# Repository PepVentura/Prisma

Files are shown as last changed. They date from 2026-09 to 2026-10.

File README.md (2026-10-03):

# Prisma
Asistente inteligente de sobremesa con Raspberry Pi 5, pantalla táctil de 7", avatar 3D y audio integrado.

**Estado actual: v0.6.** Todas las piezas de la carcasa son imprimibles: cubeta, bandeja, caja superior, capucha y piezas pequeñas. Las cotas del altavoz y del radiador se confirmarán con las piezas reales.

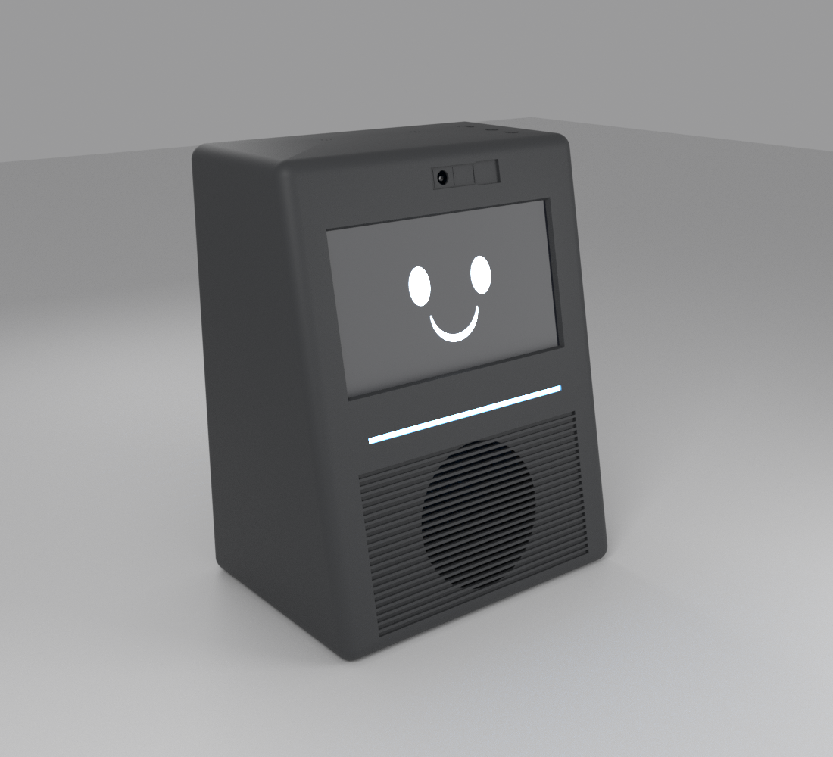
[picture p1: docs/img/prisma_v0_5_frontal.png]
Prisma v0.5


## Hardware
- Raspberry Pi 5 8 GB — confirmado
- Waveshare 7inch HDMI LCD (C), 1024×600 — recibido
- Dayton DMA105-4 — pedido
- Dayton DMA105-PR — pedido
- Dayton KABD-250 — pedido
- DAC GY-PCM5102 (PCM5102A, I²S) — propuesto
- ReSpeaker Lite USB (2 micrófonos con AEC) — propuesto
- WS2812B: barra de 8–12 LEDs y dos franjas de tira de 5 mm en los cantos (D033) — propuesto
- Cámara OV5647 5 MP, sobre la pantalla — disponible
- Fuente Mean Well GST60A24-P1J (24 V, 60 W) — propuesta
- Conversor Pololu D36V50F5 (24→5 V, 5,5 A) — propuesto

## Arquitectura
```text
Pantalla → Raspberry Pi 5 → DAC → KABD-250 → DMA105-4
                 │
                 ├── micrófonos
                 ├── LEDs
                 └── cámara
```

## Diseño (v0.5)
Frontal inclinado de arriba abajo, aristas redondeadas y negro mate, como el boceto original:
- **Arriba:** cámara con tapa deslizante y micrófonos en el techo.
- **Centro:** pantalla de 7" en horizontal.
- **Debajo:** franja LED y banda de lamas con el altavoz detrás.
- **Cantos del frontal:** dos franjas transparentes iluminadas por LEDs; el color indica el estado (escucha, pensando, silencio…).
- **Techo:** volumen y silencio de micrófonos.
- **Trasera:** ventilación, alimentación, botón de encendido y radiador pasivo.

Medidas: **205 × 262 × 150 mm**. Cámara acústica de ≈3,1 L netos. Dentro de la carcasa solo entra 24 V; la fuente de red es externa.

## CAD
`enclosure/openscad/prisma_volumetrica_v0_3.scad` es una maqueta de distribución, no la carcasa final.

`tools/comprobar_volumetrico.py` mide el volumen neto de la cámara y comprueba interferencias entre componentes.

Piezas imprimibles: la capucha (`enclosure/openscad/capucha.scad`, ver `docs/14_capucha.md`), la cubeta acústica (`enclosure/openscad/cubeta.scad`, ver `docs/15_cubeta.md`) y la bandeja, la caja superior y la balda del KABD (`bandeja.scad`, `caja_superior.scad`, ver `docs/16_bandeja_caja.md`).

`tools/simulacion_audio.py` simula la respuesta en graves del altavoz y el radiador en la cámara (ver `docs/05_audio.md`).

Consulta `docs/DECISIONS.md`, `docs/08_distribucion.md` y `docs/BOM.md`.

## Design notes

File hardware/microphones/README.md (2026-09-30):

# Micrófonos
ReSpeaker Lite USB (XMOS XU316, 2 micrófonos, AEC por hardware), 86 × 35 mm, bajo el techo. Ver `docs/10_electronica.md`.

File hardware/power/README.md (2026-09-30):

# Alimentación
Fuente Mean Well GST60A24-P1J (24 V, 60 W, externa) + conector DC de panel + Pololu D36V50F5 (24 → 5 V, 5,5 A). Presupuesto de consumo en `docs/10_electronica.md`.

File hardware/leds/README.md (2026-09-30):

# LEDs
WS2812B, 8–12 unidades inicialmente.

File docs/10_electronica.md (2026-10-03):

# 10 — Electrónica

## Esquema
```text
Fuente 24 V externa (GST60A24, 60 W)
   │  conector DC de panel (trasera)
   ├──────────────► KABD-250 (amplificador + DSP) ──► DMA105-4
   │                     ▲ entrada AUX analógica
   └─► Pololu D36V50F5 (24 → 5 V, 5,5 A)
          ├─► Raspberry Pi 5 (USB-C)
          │      ├─ I²S ──► GY-PCM5102 (DAC) ──► jack 3,5 mm ──► AUX del KABD-250
          │      ├─ HDMI + USB ──► pantalla Waveshare 7"
          │      ├─ USB ──► ReSpeaker Lite (micrófonos)
          │      ├─ CSI ──► Camera Module 3 (sobre la pantalla)
          │      └─ SPI (GPIO10) ──► 74AHCT125 ──► barra ──► franja izq. ──► franja der. (WS2812B)
          └─► alimentación de los LEDs (inyectada en la barra y en cada franja)
```

## Selección
| Función | Modelo | Por qué | Medidas |
|---|---|---|---|
| DAC | **GY-PCM5102** (PCM5102A) | El KABD-250 solo tiene entrada analógica y Bluetooth, sin I²S. Barato, bien soportado en la Pi 5 (`dtoverlay=hifiberry-dac`), 112 dB SNR, salida jack de 2,1 V rms | 32 × 14 mm |
| Micrófonos | **ReSpeaker Lite USB** (XMOS XU316, 2 micrófonos) | Cancelación de eco, supresión de ruido y ganancia automática por hardware, por USB. El XVF3800 (4 micrófonos) es mejor, pero su placa de 99 mm no cabe bajo el techo con la pantalla inclinada delante | 86 × 35 mm |
| Conversor 24 → 5 V | **Pololu D36V50F5** | 5 V, 5,5 A, entrada de 5,5 a 50 V, 80–95 % de rendimiento, muy compacto | 25,4 × 25,4 × 9,5 mm |
| Fuente | **Mean Well GST60A24-P1J** | 24 V, 2,5 A, 60 W, de sobremesa, clavija 5,5 × 2,1 mm. Da un 60 % de margen sobre el pico calculado | externa |
| Cámara | **OV5647 5 MP** (compatible con la cámara oficial v1.3; ya la tienes) | Foco fijo, 1080p. Suficiente para detectar caras y videollamadas. La Camera Module 3 (autofoco, 12 MP) tiene la misma placa y encaja en el mismo soporte | 25 × 24 mm, unos 9 mm de fondo |
| LEDs | Barra WS2812B (8–12) + 2 franjas de tira WS2812B de 5 mm a 160 LED/m (≈36 LEDs cada una, D033) + **SN74AHCT125** | La Pi da 3,3 V y los WS2812B esperan 5 V en datos: el 74AHCT125 adapta el nivel | — |

## Presupuesto de consumo (estimación)
**Rama de 5 V**

| Consumidor | Pico estimado |
|---|---:|
| Raspberry Pi 5 + Active Cooler | 15 W |
| Pantalla Waveshare 7" | 3 W |
| ReSpeaker Lite | 0,5 W |
| DAC | < 0,1 W |
| ≈84 × WS2812B (barra + franjas), corriente limitada por software a 0,6 A | 3 W (≈25 W si se encendiesen todos en blanco al 100 %: no permitido) |
| **Total** | **≈ 21,5 W → 4,3 A a 5 V** (conversor de 5,5 A: margen de 1,2 A) |

**Rama de 24 V**

| Consumidor | Pico estimado |
|---|---:|
| Conversor (21,5 W / 0,9) | 24 W |
| KABD-250, un canal a ≈10 W (límite del Xmax, ver `05_audio.md`) | 13 W |
| **Total** | **≈ 37 W** (fuente de 60 W) |

El KABD-250 recomienda 4 A porque está pensado para 2 × 50 W. Aquí solo se usa un canal y el altavoz no admite más de unos 10 W en graves, así que 2,5 A sobran.

## Conexiones
### Alimentación de la Pi 5
- Del Pololu a la Pi con un cable USB-C corto (solo alimentación) y cable de 0,5 mm² o más grueso.
- La Pi 5 solo reconoce 5 A si la fuente lo anuncia por USB-PD, y el Pololu no lo hace. Para que los USB den su corriente completa (la pantalla y los micrófonos cuelgan de ellos):
  - EEPROM (`sudo rpi-eeprom-config --edit`): `PSU_MAX_CURRENT=5000`
  - `/boot/firmware/config.txt`: `usb_max_current_enable=1`

### DAC GY-PCM5102 → Pi 5
| DAC | Pi 5 (pin) |
|---|---|
| VIN | 3,3 V (1) |
| GND | GND (6) |
| BCK | GPIO18 (12) |
| LRCK | GPIO19 (35) |
| DIN | GPIO21 (40) |
| SCK | a GND (el PCM5102A genera el reloj internamente) |

`/boot/firmware/config.txt`: `dtoverlay=hifiberry-dac`. Del jack del DAC al AUX del KABD-250 con el cable de 3,5 mm que trae la placa.

### Barra WS2812B
- Datos: GPIO10 (SPI0 MOSI, pin 19) → 74AHCT125 alimentado a 5 V → resistencia de 330 Ω → DIN del primer LED.
- Condensador de 1000 µF entre 5 V y GND en la entrada de la barra.
- Franjas (D033): cada una son dos tramos, uno en la cubeta (≈15 LEDs) y otro en la capucha (≈21 LEDs), unidos en la junta con un conector JST de 3 pines para poder abrir la carcasa. Los datos bajan por la franja izquierda y vuelven a subir por un hilo fino dentro del canal hasta la franja derecha. Los cables salen a la bahía por el extremo superior de cada canal.
- Alimentación: 5 V y GND inyectados en la entrada de la barra y en lo alto de cada franja, con cable de 0,5 mm².
- **Límite de corriente obligatorio en el software:** 0,6 A en total para los LEDs (por ejemplo, brillo global máximo de 0,25 y nunca blanco a tope en todos). Sin ese límite podrían pedir más de 4 A y tumbar la Pi.
- La librería clásica `rpi_ws281x` no funciona en la Pi 5 (su chip de E/S, el RP1, es distinto). Se controla por SPI, por ejemplo con `adafruit-circuitpython-neopixel-spi`.

## Botones (D032)
| Botón | Conexión |
|---|---|
| Volumen − | Pulsador 6 × 6 entre GPIO5 (pin 29) y GND, con *pull-up* interno |
| Volumen + | Pulsador 6 × 6 entre GPIO6 (pin 31) y GND, con *pull-up* interno |
| Silencio de micrófonos | Interruptor SS12D00 en serie con el cable rojo (+5 V) del USB del ReSpeaker Lite: los micrófonos se apagan físicamente. Opcional: el otro polo del SS12D00 a GPIO13 (pin 33) para que el software sepa el estado |
| Encendido | Pulsador al conector `PWR BUT` (J2) de la Pi 5: pulsación corta apaga bien, otra la enciende |

## Audio: filtro y cancelación de eco
- **Filtro paso alto de 40 Hz (D022) y ecualización:** en la Pi, con CamillaDSP o un filtro de PipeWire. Así no hace falta el programador DSPB-ICP1 para el DSP del KABD-250, que se queda con sus ajustes por defecto y los potenciómetros.
- **Cancelación de eco:** el ReSpeaker Lite cancela el eco por hardware si recibe como referencia el mismo audio que suena. La música sale por el DAC, así que PipeWire envía una copia al ReSpeaker por USB; su salida queda sin conectar. Si esa vía no funciona bien, la alternativa es la cancelación de eco por software de PipeWire (`module-echo-cancel`, WebRTC), que funciona con cualquier micrófono.

## Cámara (D025)
**Ubicación:** centrada en la franja del frontal inclinado, justo encima del cristal de la pantalla.

Opciones descartadas:
| Ubicación | Por qué no |
|---|---|
| Techo | Mira hacia arriba y ya lo ocupan los micrófonos |
| Franja de LEDs, entre pantalla y altavoz | Solo 11 mm de alto, demasiado baja (vería al usuario desde abajo) y pegada al altavoz, que la haría vibrar |
| Laterales | Descentrada: la cara del usuario saldría de perfil y el seguimiento del avatar quedaría torcido |
| Módulo espía diminuto en los 12 mm libres sobre la pantalla | Cabría sin cambiar la carcasa, pero con un sensor antiguo (OV5647, sin autofoco) |

**Por qué encima de la pantalla:**
- mira de frente al usuario cuando mira la pantalla, como una webcam de portátil;
- queda a la mayor altura del aparato;
- comparte la inclinación de 18° de la pantalla, así que apunta ligeramente hacia arriba, hacia la cara de quien está sentado a la mesa;
- está lo más lejos posible del altavoz.

**Espacio:** en v0.5 la cámara cabe en el bisel superior del frontal inclinado; la altura total (262 mm) sale de apilar altavoz, bandeja, pantalla y cámara.

**Montaje:** la placa se atornilla por detrás del frontal (taladros M2 de la cámara) con el objetivo en un agujero de 8 mm. El cable plano baja por detrás de la pantalla hasta el conector CSI de la Pi.

**Privacidad (D026): tapa deslizante obligatoria.**
- Corredera de 16 × 12 mm en una guía en cola de milano rebajada 1,6 mm en el frontal. Queda casi enrasada y no se puede perder.
- Se desliza 14 mm hacia la derecha para descubrir el objetivo. Dos resaltes marcan las posiciones abierta y cerrada.
- Pieza de prueba para ajustar holguras antes del frontal definitivo: `enclosure/openscad/tapa_camara_prueba.scad` → `stl/tapa_camara_prueba_v0_1.stl`. Se imprimen la placa y la corredera planas, sin soportes; si la corredera va dura o floja, ajusta `clear`.
- Además, el software encenderá un LED de la barra mientras la cámara esté activa.

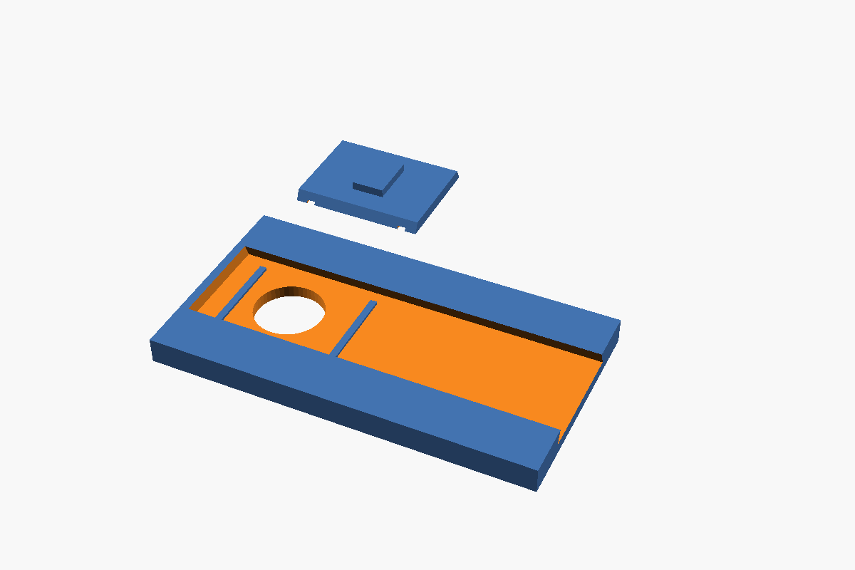
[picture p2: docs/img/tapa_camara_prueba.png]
Tapa de la cámara


## Pendiente
- Confirmar la separación real de los micrófonos del ReSpeaker Lite para situar los agujeros del techo.

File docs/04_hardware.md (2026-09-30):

# 04 — Hardware
La tabla de componentes y su estado se encuentra en `docs/BOM.md`.

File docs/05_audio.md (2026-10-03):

# 05 — Audio
## DMA105-4
4", 4 Ω, 35 W RMS. Transductor principal propuesto. Montado en el frontal inferior vertical (bafle), centrado a z ≈ 57 mm.

## DMA105-PR
4", radiador pasivo propuesto. Montado en la trasera inferior, coaxial con el DMA105-4 (D018). La trasera inferior queda libre: sin puertos, rejillas ni ventilador delante del radiador.

## Cámara acústica (D008, D016)
Forma en L:
- bloque inferior: ancho y fondo completos, de z = 3 a z = 111 mm;
- bloque superior-trasero: desde y = 60 mm hasta la trasera, de z = 111 a z = 176 mm, detrás de la pantalla.

**Actualización v0.6:** con la bandeja y la caja superior modeladas, el neto medido es de **3,08 L**. Simulación repetida: radiador + 10 g → 43,9 Hz, 10 W y 93,8 dB a 100 Hz. Sin cambios apreciables.

**Actualización v0.5:** con el frontal inclinado (D031) el altavoz queda inclinado 11° hacia el usuario y el neto final es de unos **3,13 L**. Los resultados de la simulación no cambian.

**Actualización v0.4:** con la cubeta real (anillos de montaje y aire delante de los conos), el neto final es de unos **3,1 L**. Repetida la simulación con 3,1 L, los resultados no cambian de forma apreciable. Ver `docs/15_cubeta.md`.

Volumen medido sobre el modelo v0.3 (`tools/comprobar_volumetrico.py`):

| Concepto | Litros |
|---|---:|
| Aire interior descontando DMA105-4 y DMA105-PR | 3,40 |
| Reserva para refuerzos, espuma y cableado | −0,10 |
| **Volumen neto estimado** | **≈ 3,30** |

Dentro del objetivo de 3–4 L. El desplazamiento de los transductores se modela como troncos de cono conservadores; conviene sustituirlo por las cotas reales de Dayton cuando se confirmen.

Solo con un bloque inferior (como en v0.2) la cámara se quedaba en ≈ 2,5 L netos. El bloque superior-trasero es lo que permite llegar al objetivo sin cambiar la envolvente.

## Simulación de graves
`tools/simulacion_audio.py` resuelve el modelo Thiele-Small del altavoz, el radiador y la caja con pérdidas (QL = 7). Radiación en semiespacio (sobre una mesa), a 1 m. Parámetros de las hojas de datos de Dayton:

| | DMA105-4 | DMA105-PR |
|---|---|---|
| Fs | 72,7 Hz | 37,9 Hz |
| Qts / Qms | 0,51 / 2,6 | — / 7,8 |
| Vas | 4,25 L | 2,5 L |
| Mms | 4,5 g | 29,3 g (sin masa añadida) |
| Sd | 54,1 cm² | 54,1 cm² |
| Xmax | 2,5 mm | 9 mm |

Resultados con 3,3 L netos:

| Caso | Sintonía | F3 | Potencia hasta Xmax (≥ 40 Hz) | SPL máx. a 100 Hz |
|---|---:|---:|---:|---:|
| Caja cerrada (sin PR) | — | 113 Hz | 8,0 W | 92 dB |
| PR sin masa | 50 Hz | 104 Hz | 3,3 W | 89 dB |
| **PR + 10 g** | **43 Hz** | **106 Hz** | **10,6 W** | **94 dB** |
| PR + 20 g | 39 Hz | 107 Hz | 10,0 W | 94 dB |

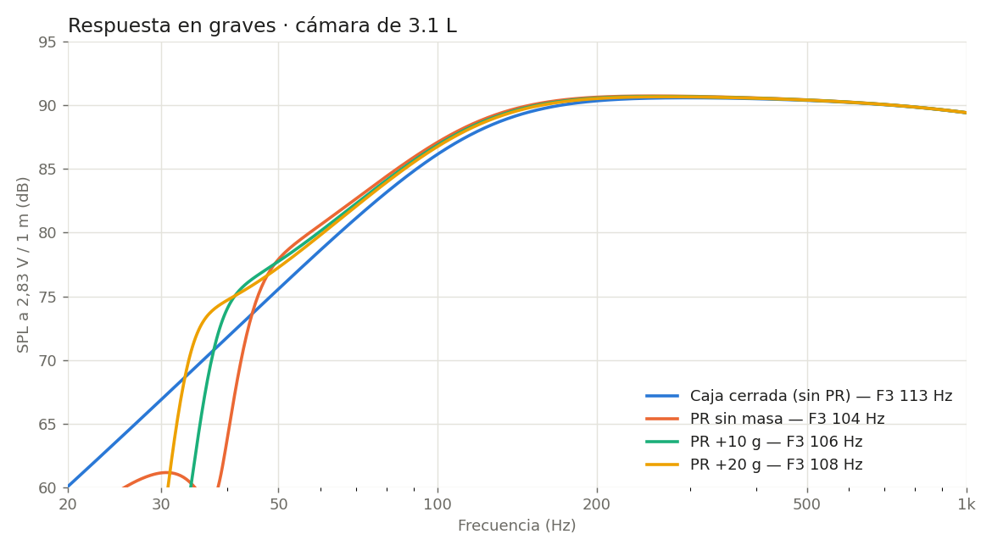
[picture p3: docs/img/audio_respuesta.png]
Respuesta en graves


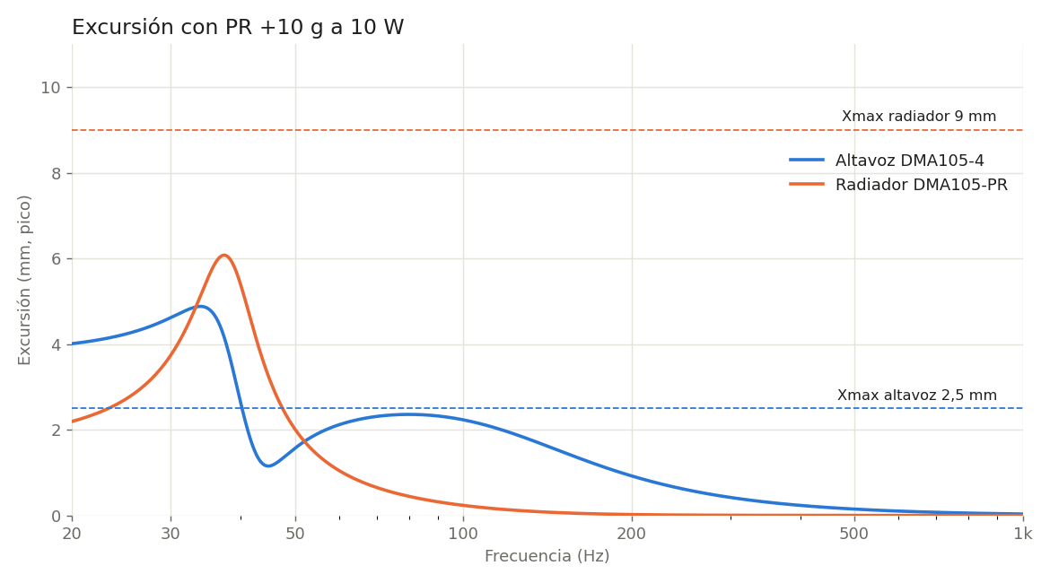
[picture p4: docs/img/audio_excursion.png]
Excursión con PR + 10 g


### Conclusiones
- **La pareja DMA105-4 + DMA105-PR funciona en 3,3 L.** El radiador no baja mucho la F3, porque un altavoz de 4" con Qts 0,51 en una caja pequeña da una F3 cercana a 105 Hz en cualquier caso. Lo que sí aporta es un colchón de graves entre 40 y 80 Hz (unos 3–5 dB más que en caja cerrada) y más potencia antes de llegar al Xmax del altavoz.
- **Masa añadida recomendada: unos 10 g** en el vástago roscado del radiador, para sintonizar a unos 43 Hz. Sin masa, la sintonía queda en 50 Hz y el altavoz se descarga justo por debajo, lo que limita la potencia útil a unos 3 W. Con 20 g apenas cambia nada respecto a 10 g.
- **Filtro paso alto obligatorio a unos 40 Hz** (Butterworth de 2.º orden o más). Por debajo de la sintonía el altavoz queda sin carga y supera su Xmax con muy poca potencia. El KABD-250 lleva DSP, así que el filtro puede ir ahí.
- **Límite práctico: unos 10 W de graves por altavoz**, que dan unos 94 dB a 100 Hz y unos 100 dB en medios a 1 m. Es de sobra para una habitación.
- **Margen con DSP:** una subida suave de graves (+4 a +6 dB a 60–80 Hz) extendería la respuesta hacia 70 Hz, a cambio de bajar el volumen máximo. Conviene ajustarla de oído con el aparato montado.
- Las paredes de la cámara, la espuma y las fugas reales cambiarán algo estos números. Hay que confirmarlo midiendo con un micrófono y REW cuando esté montado.

## Pendiente
- Refuerzos internos y posición de la espuma.
- Paso estanco de cables del altavoz (pasamuros sellado en la tapa de la cámara).

La cámara acústica debe quedar aislada del compartimento electrónico.

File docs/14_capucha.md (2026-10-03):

# 14 — Capucha (pieza 3) · v0.2

Prisma v0.5, frontal

Es la parte de la carcasa que queda por encima de la cubeta acústica (z > 108 mm).
- **Archivo:** `enclosure/openscad/capucha.scad`.
- **STL:** `stl/capucha_v0_3.stl` y sus piezas sueltas.

## División de la carcasa (D027)
| Pieza | Medidas | Material | Orientación |
|---|---|---|---|
| 1. Cubeta acústica | 205 × 148 × 108 mm | PLA negro mate | De pie |
| 2a. Bandeja delantera | 198 × 28 × 5 mm | PLA | Plana (ver `16_bandeja_caja.md`) |
| 2b. Caja superior de la cámara (suelo de la electrónica) | 198 × 98 × 79 mm | PETG | Boca abajo (ver `16_bandeja_caja.md`) |
| **3. Capucha** | **205 × 129 × 154 mm** | **PLA negro mate** | **Boca abajo (techo en la cama)** |

## Diseño (D031)
Vuelve al boceto original: frontal inclinado de arriba abajo, aristas redondeadas (r = 9 mm), laterales lisos y negro mate. En negro mate las líneas de capa apenas se ven, así que se quitan las estrías (D028 queda sin efecto).

## Qué lleva
| Elemento | Detalle |
|---|---|
| Pantalla | Ventana del área visible + 0,5 mm con chaflán de 1,5 mm. 4 resaltes con cartabón a 45° para tornillos M2.5 × 6 |
| Cámara | Agujero de 8 mm, 4 resaltes M2 y guía en cola de milano con zona de entrada para la tapa deslizante (D026) |
| Franja LED | Ranura de 142 × 3 mm entre la banda de lamas y la pantalla. Difusor transparente aparte (D033) |
| Franjas de los cantos (D033) | Ranura de 4 mm a 10,5 mm de cada lateral, justo dentro del redondeo. Detrás, un canal cerrado de 7 × 6 mm para la tira WS2812B de 5 mm, con salida de cables a la bahía por arriba. Abajo lo cierra la muesca de la bandeja |
| Micrófonos | 2 grupos de 7 agujeros de 1,2 mm en el techo y raíles para el ReSpeaker Lite |
| Botones (D032) | En el techo, a la derecha: dos capuchones de 8 mm (volumen − y +) y el interruptor deslizante de silencio, con un punto para pintar en rojo que queda a la vista al silenciar. Placa de botones atornillada por dentro |
| Trasera | Perforado de puntos de 3,5 mm (ventilación), conector DC y botón de encendido de 8 mm |
| Uniones (D029) | 2 pasadores delante (19 mm detrás del frontal, para dejar sitio al canal de las franjas), que encajan en la bandeja, y 2 tornillos M3 avellanados detrás, a la caja superior |

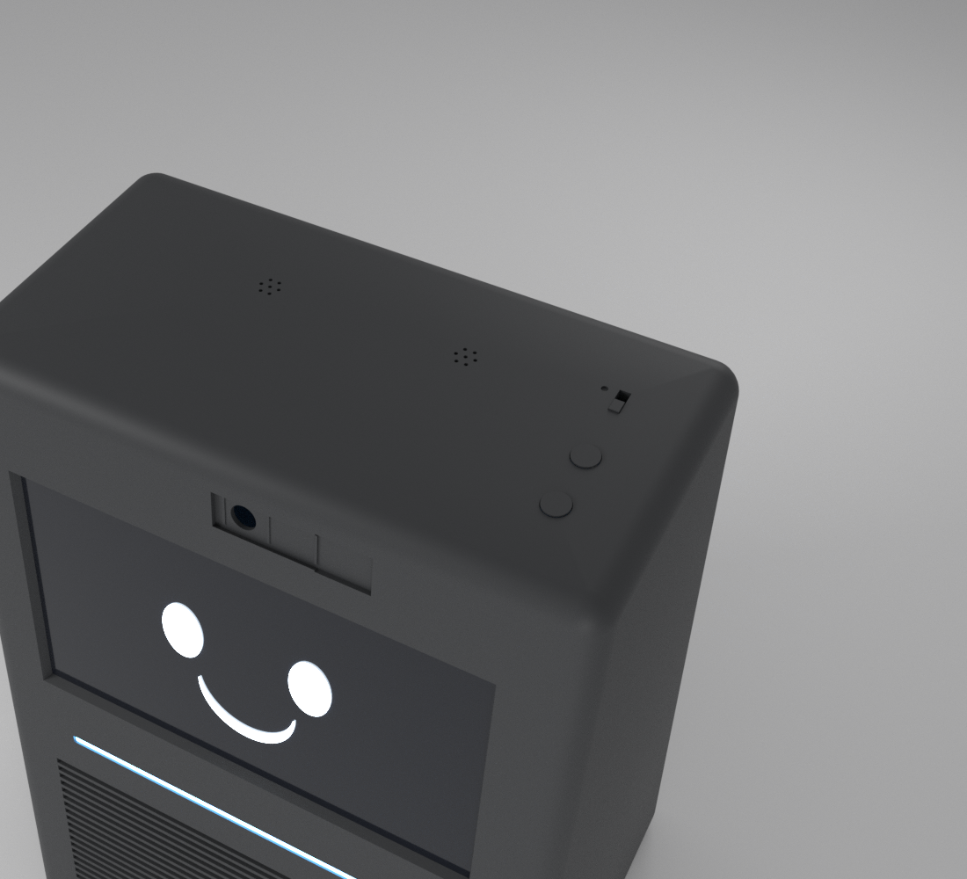
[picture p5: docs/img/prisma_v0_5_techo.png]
Techo con los botones


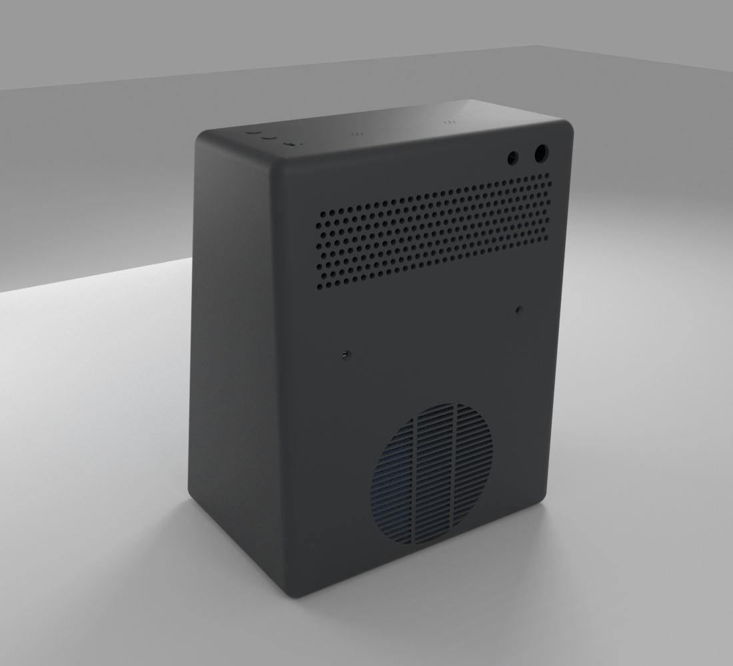
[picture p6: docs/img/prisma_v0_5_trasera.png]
Trasera


## Piezas sueltas
| STL | Material | Notas |
|---|---|---|
| `capuchones_botones_v0_1.stl` | PLA negro | Volumen −, volumen + y uno liso para el encendido. Asoman 0,5 mm y la pestaña interior los retiene |
| `deslizador_silencio_v0_1.stl` | PLA negro | Mando del SS12D00. Entra a presión en la palanca |
| `placa_botones_v0_1.stl` | PLA o PETG | Lleva 2 pulsadores de 6 × 6 × 5 mm y el SS12D00. Se fija con 2 tornillos M2 |
| `difusor_led_v0_2.stl` | PETG o PLA transparente | Se pega por dentro con su pestaña |
| `franja_sup_v0_1.stl` | PETG o PLA transparente | Tramo superior de las franjas (2 iguales). Entra deslizando por abajo, antes de montar la capucha; una gota de pegamento lo fija |
| `tapa_camara_corredera_v0_2.stl` | PLA negro | Usa la holgura que te haya ido bien con la pieza de prueba |

## Impresión
- **Capucha:** boca abajo, con el techo sobre la cama. PLA negro mate, capa de 0,2 mm, 3 perímetros y 15 % de relleno; unos 305 cm³.
- **Aristas redondeadas que tocan la cama:** solo los últimos 2–3 mm del redondeo superan los 45°. Con PLA y buena ventilación salen sin soportes.

## Comprobación
`python3 tools/comprobar_capucha.py` comprueba que la malla está cerrada, que cabe en la cama y que no choca con los componentes.

## Pendiente de verificar
- Posición de los micrófonos del ReSpeaker Lite (los grupos de agujeros toleran ±3 mm).
- Alto del objetivo de la cámara (`cam_standoff`).
- Ajuste del deslizador sobre la palanca del SS12D00 y del capuchón sobre el pulsador.

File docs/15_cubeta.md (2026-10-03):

# 15 — Cubeta acústica (pieza 1) · v0.4

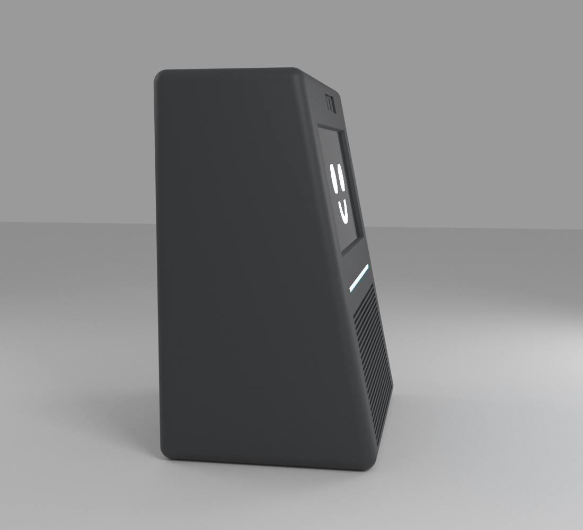
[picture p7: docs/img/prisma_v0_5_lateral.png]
Lateral


Es la parte inferior de la carcasa (z 0–108 mm) y forma el bloque principal de la cámara acústica.
- **Archivo:** `enclosure/openscad/cubeta.scad`.
- **STL:** `stl/cubeta_v0_4.stl` (205 × 148 × 108 mm, unos 390 cm³) y `stl/pata_tpu_v0_2.stl` (× 4).

## Banda de lamas y altavoz (D030, D031)
- **Banda de lamas:** el frontal inclinado lleva una banda horizontal de lamas de 2,4 mm cada 4 mm, a todo lo ancho (22 mm de margen por lado).
- **Delante del cono:** dentro de un círculo de 86 mm las lamas atraviesan la pared y dejan salir el sonido.
- **Resto de la banda:** es decorativo. Las lamas solo tienen 1,8 mm de fondo, así que la cámara queda cerrada.
- **Montaje del altavoz:** va por dentro, sobre un anillo paralelo al frontal que deja 7 mm hasta la rejilla, y queda inclinado 11° hacia el usuario.
- **Radiador:** va detrás, con una rejilla circular de 94 mm y un anillo de 14 mm (su recorrido llega a 9 mm).
- **Fijación:** 4 insertos M3 por anillo (±44,9 mm según la tienda, **medir**) y junta de espuma de 2 mm.

## Resto de la pieza
| Elemento | Detalle |
|---|---|
| Rebordes interiores | Delante (a todo lo ancho, D034), en los laterales y en la trasera (fuera del radiador), con chaflán a 45°. Ahí apoyan la bandeja (2a) y la caja superior (2b). 4 insertos M3 en los laterales para los tornillos de la caja |
| Resaltes de la bandeja | 2, junto al frontal y a 25 mm de cada lateral, con inserto M3 |
| Refuerzos | 2 nervios verticales por lateral |
| Patas | 4 alojamientos de 16 mm para patas de TPU de 5 mm |
| Franjas de luz (D033) | Ranura de 4 mm en cada canto del frontal y canal cerrado detrás para la tira WS2812B. El canal está separado de la cámara acústica y solo se abre por arriba, hacia la capucha. El inserto transparente `franja_inf_v0_1.stl` (2 iguales) entra deslizando desde arriba |

## Volumen de la cámara
`tools/comprobar_cubeta.py` mide el volumen real:

| Concepto | Litros |
|---|---:|
| Aire del volumétrico | 3,54 |
| Ocupado por la cubeta (incluidos los canales de las franjas) | −0,13 |
| Aire delante de los conos (fuera de la caja) | −0,15 |
| Reserva (espuma, cableado) | −0,10 |
| Paredes de la caja superior (2b, medidas) | −0,07 |
| **Neto** | **≈ 3,08** (ver `16_bandeja_caja.md`) |

La simulación con 3,1 L ya está hecha (ver `05_audio.md`): radiador + 10 g, sintonía ≈ 44 Hz, ≈ 10 W útiles y ≈ 94 dB a 100 Hz.

## Impresión
- De pie, suelo en la cama, PLA negro mate, 3–4 perímetros, 20 % de relleno. Sin soportes.
- Patas en TPU al 100 %.
- Insertos de las franjas: PETG o PLA transparente, tumbados con la cara vista sobre la cama (la textura de la cama los deja esmerilados y difunden mejor).

## Pendiente de verificar con las piezas reales
- Taladros, recortes y grosor del marco del altavoz y del radiador.
- Cuánto sobresale la suspensión de cada cono por delante del marco (`drv_clear`, `pr_clear`).

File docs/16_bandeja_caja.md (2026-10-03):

# 16 — Bandeja (2a), caja superior (2b) y balda del KABD · v0.1

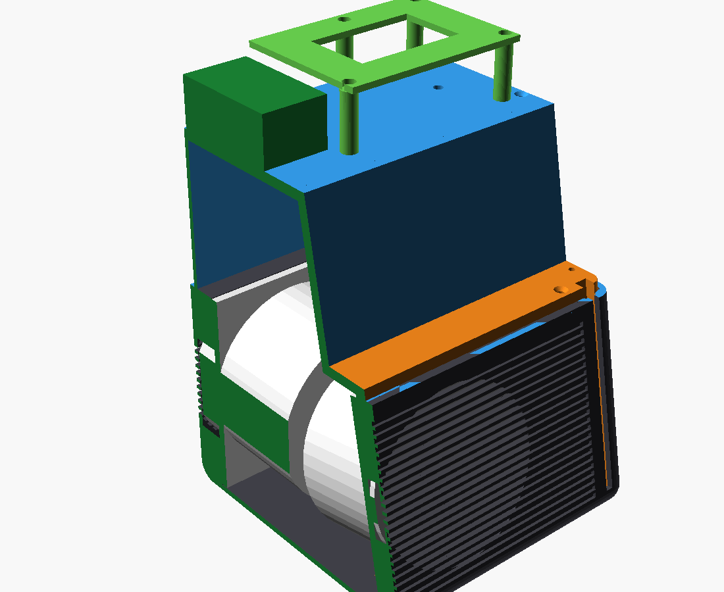
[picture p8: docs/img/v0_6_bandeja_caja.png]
Bandeja, caja superior y balda (corte)


Cierran la cámara acústica por arriba y forman el suelo de la bahía de electrónica (D027, D034).
- **Archivos:** `enclosure/openscad/bandeja.scad` y `enclosure/openscad/caja_superior.scad`.
- **STL:** `stl/bandeja_v0_1.stl`, `stl/caja_superior_v0_1.stl` (ya girada para imprimir) y `stl/balda_kabd_v0_1.stl`.

| Pieza | Medidas | Material | Impresión |
|---|---|---|---|
| 2a. Bandeja | 198 × 28 × 5 mm | PLA negro | Plana, sin soportes |
| 2b. Caja superior | 198 × 98 × 79 mm, unos 225 cm³ | PETG | Boca abajo (tapa en la cama), sin soportes |
| Balda del KABD-250 | 97 × 71 × 31 mm | PLA o PETG | Placa en la cama, patas hacia arriba |

## Bandeja (2a)
- Placa de 5 mm entre el frontal y el tabique (z 108–113). Es el techo del bloque inferior de la cámara delante del tabique.
- Apoya en el **reborde delantero** de la cubeta (nuevo, a todo lo ancho), en los rebordes laterales y en el anillo del altavoz, con burlete de espuma debajo.
- 2 tornillos M3 × 10 avellanados delante, a insertos de la cubeta (a 25 mm de cada lateral). Por detrás la pisa el tabique de la caja superior.
- Agujeros para los 2 pasadores de la capucha (D029) y muescas que cierran el canal de las franjas de luz (D033).
- El borde delantero queda 1 mm retrasado respecto a la pared: la capucha baja en vertical y, por la inclinación del frontal, su pared avanza ≈1 mm en los últimos 5 mm de recorrido.

## Caja superior (2b)
- Tabique inclinado de 5 mm paralelo al frontal (detrás de la pantalla), laterales y trasera de 2,5 mm y tapa de 5 mm. Abierta por abajo.
- Holgura de 0,3 mm con la capucha por todos lados.
- Apoya en los rebordes laterales y trasero de la cubeta y en el anillo del radiador, y el tabique pisa la parte trasera de la bandeja. Burlete de espuma en todo el apoyo.
- **Fijación:** 4 tubos verticales con tornillos M3 × 80 avellanados desde la tapa hasta los insertos de los rebordes laterales (y = 80 y 135 mm).
- **Capucha:** 2 resaltes con inserto M3 en la trasera, a la altura de los tornillos traseros de la capucha (D029).
- **Cables del altavoz:** agujero de 5 mm en la tapa (detrás, a la derecha). Se sella con silicona neutra después de pasar los cables.
- **Bahía:** la tapa queda lisa por fuera para poder imprimirla sobre la cama. Lleva insertos ciegos (4 mm en una tapa de 5, así que no abren la cámara):
  - 4 insertos M2.5 para la Pi 5, con separadores de nailon M2.5 × 3 mm;
  - 4 insertos M3 para las patas de la balda.
- El conversor y el DAC se fijan con cinta de doble cara o velcro.

## Balda del KABD-250
- Placa de 3 mm sobre 4 patas de 28 mm, encima de la Pi 5. Las patas evitan los puertos de la Pi, el conversor y el DAC.
- Tornillos M3 × 35 desde arriba, por dentro de las patas, hasta los insertos de la tapa.
- Los taladros del KABD-250 se añadirán cuando llegue y se pueda medir.

## Volumen de la cámara con todas las piezas
`python3 tools/comprobar_camara.py` comprueba las tres piezas (mallas, cama, choques con la cubeta, la capucha y los componentes) y mide el volumen neto:

| Concepto | Litros |
|---|---:|
| Aire del volumétrico | 3,54 |
| Cubeta (anillos, rebordes, canales de las franjas) | −0,13 |
| Caja superior (paredes, tubos, resaltes) | −0,07 |
| Aire delante de los conos | −0,15 |
| Reserva (espuma, cableado) | −0,10 |
| **Neto** | **≈ 3,08** |

Con 3,08 L la simulación apenas cambia: radiador + 10 g, sintonía ≈ 44 Hz, ≈ 10 W y ≈ 94 dB a 100 Hz.

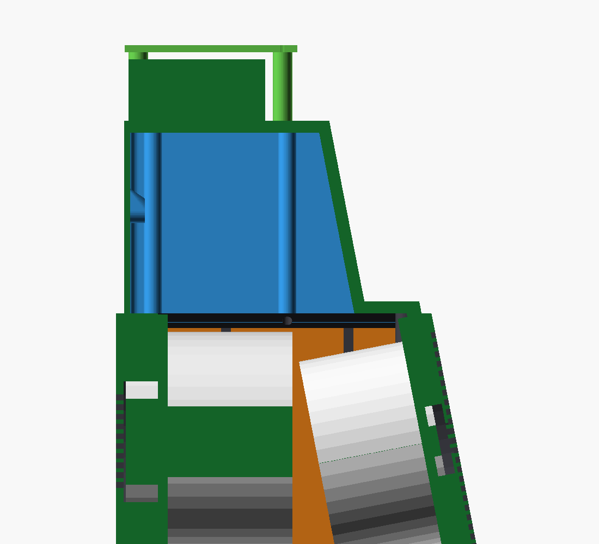
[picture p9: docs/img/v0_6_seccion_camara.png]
Corte lateral


## Orden de montaje de la cámara
1. Insertos en la cubeta: 4 del altavoz, 4 del radiador, 2 de la bandeja y 4 de los rebordes laterales.
2. Altavoz y radiador con su junta de espuma. Relleno acústico.
3. Franjas inferiores: tira de LEDs y conector en el canal, inserto transparente deslizado desde arriba.
4. Burlete en el reborde delantero, los laterales y el anillo. Bandeja con sus 2 tornillos.
5. Cables del altavoz por el agujero de la tapa, sellado con silicona. Burlete en los apoyos de la caja superior, caja en su sitio y 4 tornillos M3 × 80.
6. Bahía: Pi 5, conversor, DAC y balda con el KABD-250.
7. Capucha: pasadores delante y 2 tornillos M3 detrás.

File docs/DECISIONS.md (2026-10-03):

# Decisiones
| ID | Decisión | Estado |
|---|---|---|
| D001 | Raspberry Pi 5 8 GB | Cerrada |
| D002 | Waveshare 7", montada en horizontal (apaisada) para vídeo | Cerrada |
| D003 | Fuente AC/DC externa (nada de red 230 V dentro de Prisma) | Cerrada |
| D004 | Bus interno 24 V + buck 5 V | En desarrollo |
| D005 | DMA105-4 | Propuesta |
| D006 | DMA105-PR con ≈10 g de masa añadida (sintonía ≈43 Hz, validado por simulación) | Propuesta |
| D007 | KABD-250 | Propuesta |
| D008 | Cámara acústica independiente y estanca | Cerrada |
| D009 | Envolvente 205×262×150 mm con frontal inclinado continuo (v0.5). Cámara acústica ≈3,1 L netos | Provisional |
| D010 | OpenSCAD | Cerrada |
| D011 | DAC GY-PCM5102 (PCM5102A) por I²S → AUX del KABD-250 | Propuesta |
| D012 | Micrófonos ReSpeaker Lite USB (2 micrófonos, AEC por hardware) bajo el techo | Propuesta |
| D013 | Fuente Mean Well GST60A24-P1J (24 V, 60 W) | Propuesta |
| D014 | Conversor Pololu D36V50F5 (5 V, 5,5 A) | Propuesta |
| D015 | ~~Frontal inferior vertical + superior inclinado 18°~~ Sustituida por D031 | Sustituida |
| D016 | Cámara acústica en L: bloque inferior de ancho y fondo completos + bloque superior-trasero detrás de la pantalla | Propuesta (v0.3) |
| D017 | Electrónica en bahía superior sobre la tapa de la cámara: Pi 5, buck y DAC en el suelo; KABD-250 en una balda encima (lado derecho). Ventilación pasiva solo en la bahía (rejillas trasera superior y laterales). Ningún ventilador ni rejilla en la zona de la cámara | Propuesta (v0.3) |
| D018 | DMA105-PR en la trasera inferior, coaxial con el DMA105-4 | Propuesta (v0.3) |
| D019 | Trasera: entrada DC 24 V de panel en la bahía superior. Los puertos de la Pi no salen al exterior; si hace falta USB/HDMI externo, alargador de panel | Propuesta (v0.3) |
| D020 | Micrófonos en el techo, en la zona trasera (lo más lejos posible del DMA105-4). Cámara opcional: posición pendiente | Propuesta (v0.3) |
| D021 | Conexión de la pantalla con clavijas acodadas: HDMI (cable plano o adaptador a 90° → micro-HDMI de la Pi) y micro-USB táctil acodado. Hueco lateral reservado de 15 mm | Propuesta (v0.3) |
| D022 | Filtro paso alto a ≈40 Hz en la Pi (CamillaDSP/PipeWire) para proteger el altavoz por debajo de la sintonía | Propuesta |
| D023 | LEDs WS2812B por SPI (GPIO10) con adaptador de nivel SN74AHCT125 | Propuesta |
| D024 | Cancelación de eco por hardware en el ReSpeaker Lite; alternativa por software en PipeWire | Propuesta |
| D025 | Cámara OV5647 5 MP (compatible v1.3; la Camera Module 3 también encaja) centrada sobre la pantalla, en el frontal inclinado (mira al usuario con la inclinación de la pantalla). La carcasa crece 16 mm de alto para alojarla | Propuesta |
| D026 | Tapa deslizante de privacidad sobre la cámara, integrada en el frontal (guía en cola de milano), más LED de aviso cuando la cámara está activa | Cerrada |
| D027 | Carcasa en 4 piezas: cubeta acústica (PLA), bandeja (PLA), caja superior de la cámara (PETG) y capucha desmontable (PLA). La Kobra X imprime 260 mm y la carcasa mide 266 | Propuesta |
| D028 | ~~Estrías horizontales en laterales y trasera~~ Sin efecto con el acabado negro mate de D031 | Sustituida |
| D029 | Uniones de la capucha: 2 pasadores delanteros en la bandeja y 2 tornillos M3 avellanados traseros a insertos de la caja superior | Propuesta |
| D030 | Rejillas integradas en la cubeta (banda de lamas delante, circular detrás); altavoz y radiador montados por dentro sobre anillos de 7 y 14 mm con insertos M3 | Cerrada |
| D031 | Vuelta al boceto original: frontal inclinado 11° continuo de arriba abajo, aristas redondeadas, banda de lamas a todo lo ancho bajo la pantalla, laterales lisos, negro mate. 205 × 262 × 150 mm. La parte alta de la cámara acústica queda tras un tabique paralelo al frontal | Cerrada |
| D034 | Bandeja y caja superior: bandeja de 5 mm sobre un reborde delantero nuevo de la cubeta, con 2 tornillos; caja superior abierta por abajo, fijada con 4 tornillos M3 × 80 por tubos desde el suelo de la bahía; burlete de espuma en todos los apoyos; tapa lisa con insertos ciegos para la Pi y la balda del KABD | Propuesta |
| D033 | Luz de acento: franjas de 4 mm en los dos cantos del frontal y difusor de la barra, impresos en filamento transparente; el color lo dan tiras WS2812B de 5 mm (160 LED/m) según el estado del asistente (escucha, pensando, hablando, silencio, avisos). El marco de color alrededor de la pantalla lo dibuja el software | Cerrada |
| D032 | Botones: volumen − y + con capuchones de 8 mm enrasados en el techo, interruptor deslizante que corta la alimentación USB del ReSpeaker (silencio real) y botón de encendido trasero al conector de la Pi 5 | Cerrada |

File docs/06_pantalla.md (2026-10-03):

# 06 — Pantalla
Modelo: Waveshare 7inch HDMI LCD (C) Rev4.1, 1024×600, IPS, táctil capacitivo (USB).

**Orientación: horizontal (apaisada)**, para ver vídeo (YouTube, etc.) a pantalla completa. Es la orientación nativa del panel, así que no hace falta rotar nada en el sistema.

1024×600 es un formato ≈ 17:10. Un vídeo 16:9 ocupa todo el ancho y deja dos franjas negras finas, de unos 12 píxeles, arriba y abajo.

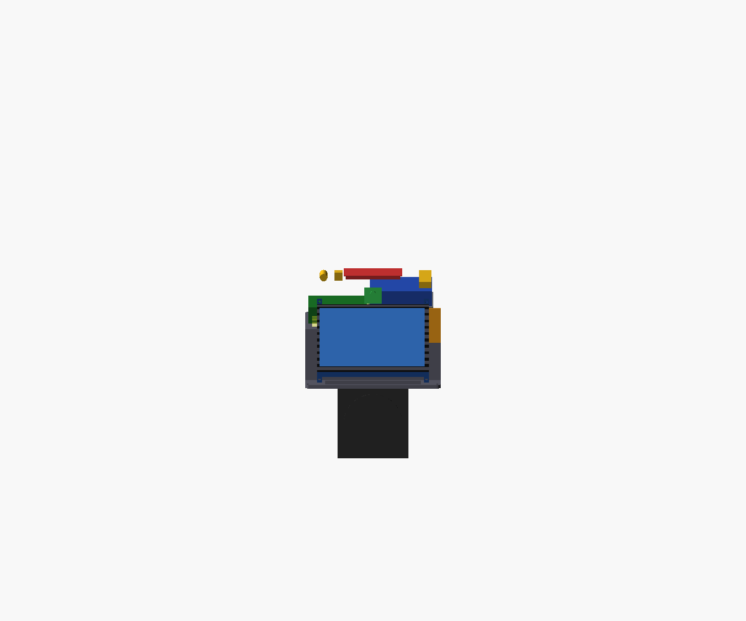
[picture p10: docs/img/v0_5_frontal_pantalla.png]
Frontal v0.5


## Medidas
Las cotas del PCB, los taladros y los conectores salen del plano oficial de Waveshare. Las del cristal y el área visible, de fotos de la unidad real (±1 mm).

| Cota | Valor | Fuente |
|---|---:|---|
| Ancho total | 164,90 mm | plano |
| Alto total con pestañas | 124,27 mm | plano |
| Alto del PCB entre pestañas | 106,96 mm | plano |
| Hueco entre pestañas (arriba) | 148,90 mm | plano |
| Taladros de fijación | 4 × 156,90 × 114,96 mm entre centros, a 4,0 mm de los laterales | plano |
| Alto del cristal | ≈ 99,8 mm | foto |
| Área visible | 154,21 × 85,92 mm | hoja de datos |
| Margen cristal → área visible | izq. ≈ 3,6 · der. ≈ 7,1 · sup. ≈ 4,9 · inf. ≈ 9,0 mm | foto |
| Cristal → cara trasera del PCB | 9,5 mm | medido |
| Conectores detrás del PCB | 7 mm (HDMI) | medido |
| Diámetro de los taladros | 3,0 mm → tornillos M2.5 | medido |

## Conectores
Mirando la pantalla de frente, con el flex del LCD abajo:
- todos en el **canto derecho**, en la mitad superior;
- de arriba abajo, medido desde el borde superior de las pestañas: HDMI (18–34 mm), micro-USB del táctil (41–49 mm) e interruptor de retroiluminación (54–62 mm). El HDMI sobresale unos 2 mm del canto;
- las clavijas entran de lado (en horizontal), no por detrás.

Por eso hacen falta **clavijas acodadas** (D021):
- HDMI: cable plano HDMI-A → micro-HDMI con cabezales a 90°, o un adaptador HDMI a 90° + cable;
- táctil: cable micro-USB acodado → USB-A.

El modelo reserva 15 mm libres a la derecha del conector. Con la pantalla centrada, ese hueco llega justo a la pared interior. Cuando elijamos los cables concretos hay que confirmar que su clavija acodada cabe en 15 mm; si no, habría que desplazar la pantalla un par de milímetros a la izquierda o ensanchar la carcasa. Por esto mismo los laterales ya no se estrechan.

El interruptor de retroiluminación queda accesible solo con la carcasa abierta. Déjalo en ON.

## Marco de prueba
`enclosure/openscad/marco_pantalla_prueba.scad` → `stl/marco_pantalla_prueba_v0_1.stl` (171,5 × 130,9 × 9,9 mm, ≈55 cm³).

Sirve para comprobar el encaje real antes de imprimir la carcasa:
- ventana = área visible + 0,5 mm por lado, con chaflán de 1,5 mm hacia delante;
- 2 mm de material delante del cristal; el cristal entra desde atrás con 0,3 mm de holgura;
- el PCB solo apoya en 4 resaltes y se atornilla con **M2.5 × 6 autorroscantes** (agujero de 2,2 mm; cambiar `pilot_d` a 3,5 si prefieres insertos M2.5);
- hueco bajo el cristal para el flex del LCD;
- el canto derecho queda libre para los conectores.

**Impresión:** cara vista sobre la cama y sin soportes. PLA o PETG, capa de 0,2 mm y 3 perímetros.

**Qué comprobar al montarla:**
1. El cristal entra sin forzar y no baila (holgura: `fit`).
2. La ventana no tapa píxeles: enciende la pantalla y mira los cuatro bordes (margen: `win_margin`; si falta, revisa `screen_active_x0` y `screen_active_z0`).
3. Los taladros coinciden y el PCB queda plano sobre los resaltes, sin presionar el cristal.
4. El flex de abajo no roza.

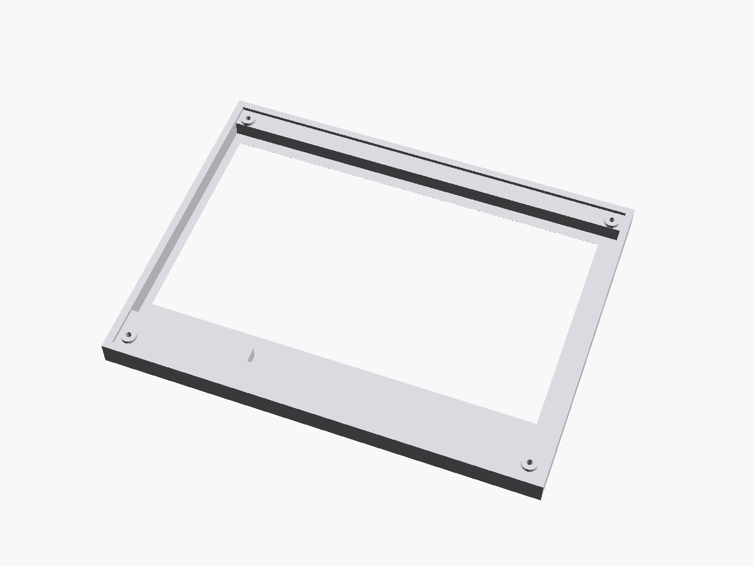
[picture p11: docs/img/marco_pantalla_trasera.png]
Marco, cara trasera


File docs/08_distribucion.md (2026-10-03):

# 08 — Distribución (v0.5)

> v0.5 cambia el perfil (D031): las tablas de abajo describen las zonas, que se mantienen. En el frontal, de abajo arriba van la banda de lamas con el altavoz, la franja LED, la pantalla y la cámara. La parte alta de la cámara acústica queda detrás de un tabique paralelo al frontal, y la electrónica empieza a z = 187 mm.
Envolvente de trabajo: **205 × 262 × 150 mm** (ancho × alto × fondo), con el frontal inclinado 11° de arriba abajo y aristas redondeadas (D031). La altura sale de apilar en el frontal el altavoz, la bandeja de la cámara acústica, la pantalla y la cámara.

Prisma v0.5

## Perfil (D015)
- Frontal inferior vertical hasta z = 122 mm: bafle del DMA105-4 y barra LED.
- Frontal superior inclinado 18° hacia atrás: pantalla. Retranqueo arriba ≈ 41,6 mm, así que el techo mide ≈ 103 mm de fondo.
- Laterales rectos. Con el estrechamiento de 8 mm por lado no cabían las clavijas del canto derecho de la pantalla.

## Zonas
| Zona | Contenido |
|---|---|
| Frontal inferior | DMA105-4, rejilla frontal |
| Franja entre altavoz y pantalla | Barra LED WS2812B (z ≈ 116–122 mm) |
| Franja sobre la pantalla | Cámara Raspberry Pi Camera Module 3, centrada y con la misma inclinación que la pantalla (D025) |
| Frontal superior inclinado | Waveshare 7" en horizontal. Conectores en el canto derecho, mitad superior, con 15 mm libres para clavijas acodadas |
| Detrás de la pantalla | Los conectores quedan a la altura de la bahía: los cables no pasan por la zona de la cámara |
| Interior inferior + superior-trasero | Cámara acústica en L (D016) |
| Trasera inferior | DMA105-PR (D018) |
| Bahía superior (z ≥ 175 mm) | Suelo: Pi 5 con Active Cooler (izquierda), buck y DAC (derecha). Balda encima: KABD-250. Huecos de 20 mm delante de los puertos de la Pi |
| Trasera superior y laterales (altura de la bahía) | Rejillas de ventilación + entrada DC 24 V en la trasera (D017, D019) |
| Techo | ReSpeaker Lite (86 × 35 mm) justo bajo el techo, zona trasera, con 2 agujeros para los micrófonos. Cámara opcional: posición pendiente |

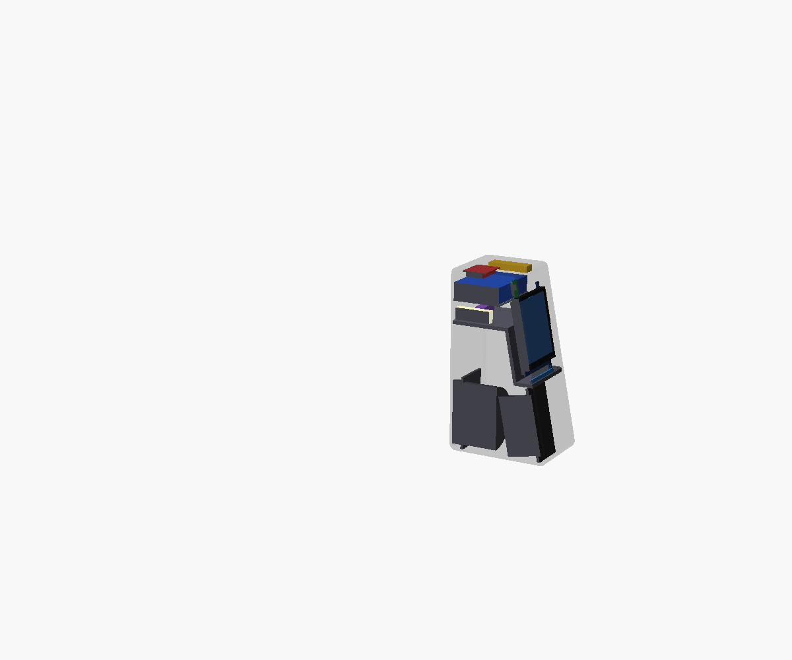
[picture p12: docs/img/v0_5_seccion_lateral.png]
Sección lateral v0.5


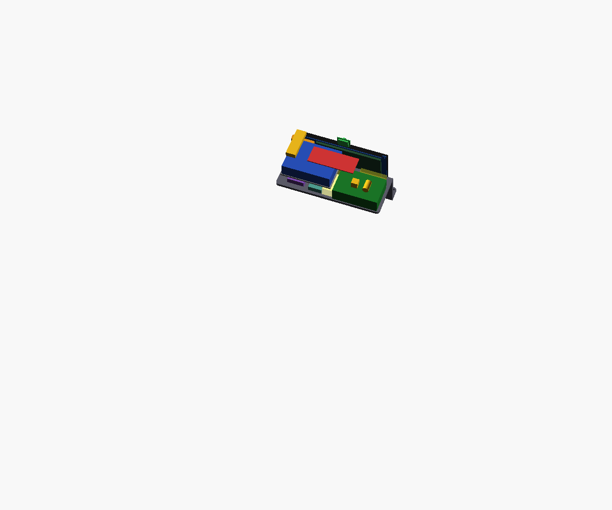
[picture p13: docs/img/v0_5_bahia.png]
Bahía de electrónica


## Criterios
- Todo el calor queda en la bahía superior, ventilada por rejillas en la trasera y en los laterales. Nada de ventiladores junto a la cámara.
- La Pi va en orientación normal. Sus USB miran a la derecha, hacia el hueco libre (ahí va el cable táctil). Los micro-HDMI y el USB-C miran hacia la pantalla.
- El cable HDMI va del canto derecho de la pantalla, delante del KABD-250, hasta el micro-HDMI de la Pi.
- Micrófonos lo más lejos posible del altavoz y desacoplados de la carcasa.

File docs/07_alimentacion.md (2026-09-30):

# 07 — Alimentación
Fuente AC/DC externa de 24 V (D003). **No hay fuente de red dentro de Prisma.**

Dentro de Prisma:
- conector DC 24 V de panel en la trasera, a la altura de la bahía de electrónica (D019);
- KABD-250 alimentado a 24 V;
- buck 24→5 V sobre el soporte encima del KABD-250;
- distribución de 5 V a Pi, pantalla y periféricos.

La potencia/corriente definitiva se calculará antes de comprar fuente y buck. Recordatorio: la Pi 5 pide 5 V / 5 A para dar corriente completa a los USB, así que el buck debe ir sobrado.

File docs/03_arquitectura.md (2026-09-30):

# 03 — Arquitectura
```text
Waveshare 7"
     │
     ▼
Raspberry Pi 5
 ├── STT / LLM / TTS
 ├── Avatar
 ├── Micrófonos
 ├── LEDs
 └── DAC ──► KABD-250 ──► DMA105-4

DMA105-PR = parte trasera de la cámara acústica
```

Alimentación:
```text
24 V externo
 ├── KABD-250
 └── Buck 24→5 V ──► Pi / pantalla / periféricos
```

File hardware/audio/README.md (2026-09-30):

# Audio
DMA105-4 (frontal inferior) + DMA105-PR (trasera inferior) + KABD-250 como arquitectura propuesta. Cámara en L de ≈3,3 L netos; ver `docs/05_audio.md`.

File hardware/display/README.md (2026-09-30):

# Display
Waveshare 7inch HDMI LCD (C). La geometría exacta de montaje queda pendiente de verificar con la unidad física.

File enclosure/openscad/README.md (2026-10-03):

# OpenSCAD v0.5
Abrir `prisma_volumetrica_v0_5.scad`. Todas las cotas están en `parametros.scad`.

Es un modelo de distribución. No es todavía la carcasa final.

## Interruptores útiles (en `parametros.scad` o con `-D`)
| Variable | Efecto |
|---|---|
| `section_x = true` | Corte por el plano medio: vista lateral interior |
| `show_chamber_air = true` | Muestra el aire neto de la cámara acústica |
| `show_shell`, `show_screen`, `show_audio`, `show_electronics` | Mostrar u ocultar grupos |

## Comprobación
```bash
pip install trimesh numpy manifold3d
python3 tools/comprobar_volumetrico.py
```
Da el volumen neto de la cámara y avisa de cualquier interferencia, o de un componente que se salga de la envolvente. Conviene lanzarlo después de cambiar cualquier cota.

## Próxima revisión
- geometría real de la pantalla (medir la unidad);
- cotas reales de DMA105-4 / DMA105-PR (recorte, marco, fondo);
- paredes, refuerzos y junta de la cámara acústica;
- división en piezas imprimibles y fijaciones;
- rejillas de ventilación reales.

`capucha.scad` es la capucha imprimible (ver `docs/14_capucha.md`); `tools/comprobar_capucha.py` la comprueba.

`marco_pantalla_prueba.scad` es el marco de prueba de la pantalla (ver `docs/06_pantalla.md`).

`archivo/` contiene versiones anteriores: v0.2 y `v0_4/` (diseño con estrías y frontal partido).

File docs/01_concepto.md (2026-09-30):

# 01 — Concepto
Prisma es un asistente de sobremesa con pantalla táctil y avatar 3D.

Objetivos: voz, pantalla, avatar, TTS, lip-sync, iluminación y posible integración domótica.

La carcasa será futurista/trapezoidal y se fabricará mediante impresión 3D.

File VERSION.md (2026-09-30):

v0.3 — volumétrico de distribución
==================================
✔ Perfil lateral: frontal inferior vertical + frontal superior inclinado 18°
✔ Cámara acústica en L, ≈3,3 L netos medidos sobre el modelo
✔ Electrónica en bahía superior, sin fuente interna
✔ DMA105-PR en la trasera inferior
✔ Comprobación automática de volumen e interferencias (tools/)

Ver CHANGELOG.md y docs/DECISIONS.md.

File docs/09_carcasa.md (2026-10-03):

# 09 — Carcasa
Orden de desarrollo:
1. volumétrico — **v0.3 hecho** (perfil, zonas, cámara en L, comprobación de interferencias);
2. marco de pantalla — siguiente paso: medir la Waveshare real (espesor, pestañas, conectores);
3. cámara acústica — paredes, refuerzos, junta y pasamuros;
4. estructura interna;
5. piel exterior;
6. fijaciones;
7. ventilación;
8. detalles estéticos;
9. STL de producción.

## Requisitos del frontal definitivo
- Guía en cola de milano y tapa deslizante de la cámara (D026), según `tapa_camara_prueba.scad`.

## División en piezas
Ver `docs/14_capucha.md` (D027). La capucha v0.1 ya está diseñada; faltan la cubeta, la bandeja y la caja superior.

## Notas para la división en piezas (impresión)
- La altura de 262 mm y el frontal inclinado hacen pensar en varias piezas: cámara acústica (pieza estanca propia), bahía superior con tapa desmontable y marco frontal de la pantalla.
- La tapa de la bahía da acceso de servicio a la Pi y al resto de la electrónica sin abrir la cámara.

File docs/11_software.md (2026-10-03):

# 11 — Software
Arquitectura prevista:
`Micrófono → STT → LLM → TTS → audio + lip-sync → avatar`

La interfaz mostrará avatar, estados, respuestas, reproducción y controles táctiles.

## Luz de estado (D033)
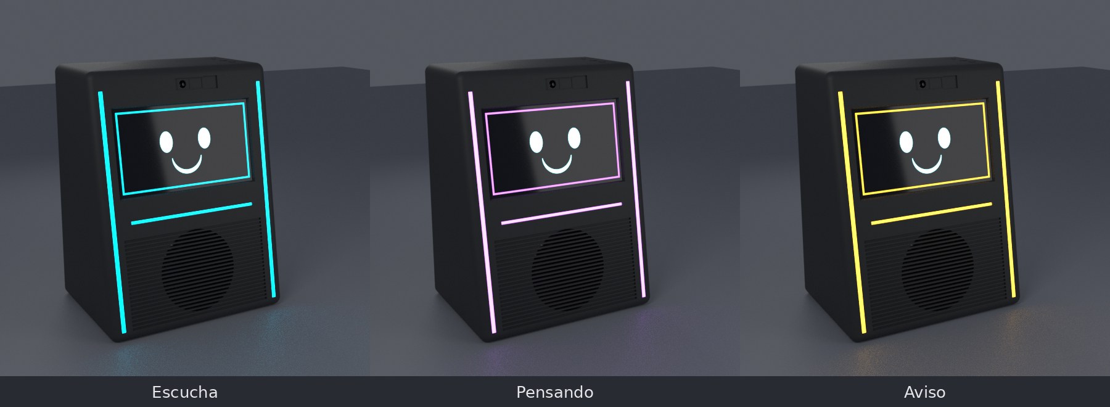
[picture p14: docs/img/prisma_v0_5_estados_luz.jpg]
Estados de luz


Las franjas de los cantos, la barra bajo la pantalla y un marco de color que la interfaz dibuja alrededor de la pantalla cambian juntos según el estado. Colores de partida (configurables):

| Estado | Franjas y barra | Marco en pantalla |
|---|---|---|
| Reposo | Apagadas o blanco cálido muy tenue (modo ambiente) | No |
| Escucha (tras la palabra de activación) | Cian fijo, sube de intensidad | Cian |
| Pensando | Pulso violeta que recorre las franjas de abajo arriba | Violeta tenue |
| Hablando | Cian; la barra sigue el volumen de la voz | Cian tenue |
| Micrófonos silenciados (interruptor, GPIO13) | Rojo tenue fijo en la barra | No |
| Aviso, temporizador o mensaje | Ámbar parpadeando despacio | Ámbar |
| Error o sin conexión | Naranja fijo | No |
| Cámara activa | Un LED blanco en lo alto de cada franja (privacidad) | — |
| Modo noche | Brillo al 10 % o apagado | — |

Límite de corriente de los LEDs: 0,6 A (ver `10_electronica.md`).

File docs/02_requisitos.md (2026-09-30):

# 02 — Requisitos
- STT → LLM → TTS.
- Avatar 3D.
- Lip-sync.
- Pantalla táctil.
- Iluminación WS2812B.
- Cámara opcional.
- Mantenimiento sencillo.
- Cámara acústica sellada y separada de electrónica.
- Carcasa desmontable e imprimible en 3D.

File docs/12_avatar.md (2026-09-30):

# 12 — Avatar
Modelo VRM renderizado con HTML5/Three.js/WebGL.

Estados:
- idle
- listening
- processing
- speaking
- notification
- error

Primera versión de lip-sync: energía/amplitud del audio TTS.

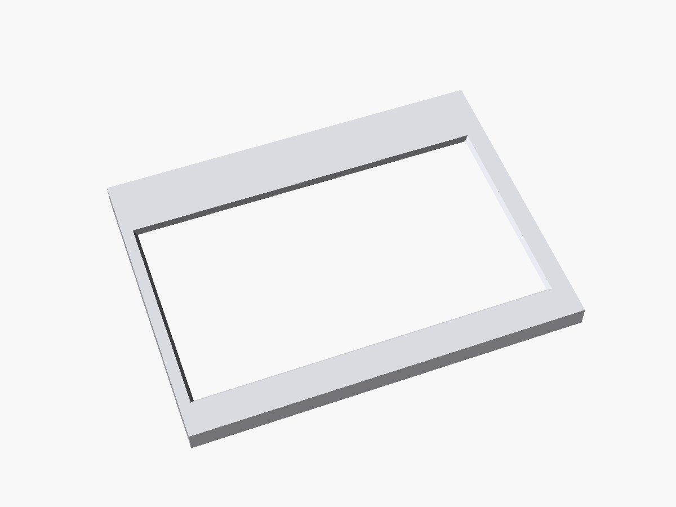
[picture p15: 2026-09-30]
docs/img/marco_pantalla_frontal.png

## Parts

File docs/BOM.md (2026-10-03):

# BOM
| Categoría | Componente | Cant. | Estado | Prioridad |
|---|---|---:|---|---|
| Raspberry Pi | Raspberry Pi 5 8 GB | 1 | Confirmado | Comprar ahora |
| Display | Waveshare 7" HDMI LCD (C) | 1 | Confirmado/recibido | Disponible |
| Audio | Dayton DMA105-4 | 1 | Propuesto | Al cerrar diseño |
| Audio | Dayton DMA105-PR | 1 | Propuesto | Al cerrar diseño |
| Amplificación | Dayton KABD-250 | 1 | Propuesto | Al cerrar diseño |
| Audio | GY-PCM5102 (DAC I²S PCM5102A) | 1 | Propuesto | Al cerrar diseño |
| Micrófonos | ReSpeaker Lite USB (2 micrófonos, XU316) | 1 | Propuesto | Al cerrar diseño |
| Cámara | OV5647 5 MP (compatible v1.3) + cable 22→15 pines para Pi 5 | 1 | Disponible | Comprobar el cable |
| LEDs | Barra WS2812B (bajo la pantalla) | 8–12 | Propuesto | Al cerrar diseño |
| LEDs | Tira WS2812B de 5 mm, 160 LED/m, 5 V (mejor la versión COB/FCOB: luz continua sin puntos) | 1 m (se usan ≈0,95 m) | Propuesto | Al cerrar diseño |
| LEDs | Conectores JST-GH o JST-SH de 3 pines (unión cubeta ↔ capucha de cada franja) | 2 | Propuesto | Al cerrar diseño |
| Alimentación | Mean Well GST60A24-P1J (24 V, 60 W, externa) | 1 | Propuesto | Al cerrar diseño |
| Alimentación | Conector DC de panel 24 V | 1 | En estudio | Al cerrar diseño |
| Alimentación | Pololu D36V50F5 (24 → 5 V, 5,5 A) | 1 | Propuesto | Al cerrar diseño |
| Refrigeración | Pi 5 Active Cooler | 1 | Necesario | Comprar ahora |
| Acústica | Espuma/relleno acústico para la cámara | 1 | Propuesto | Al cerrar diseño |
| Acústica | Junta de estanqueidad (burlete EPDM fino) | 1 | Propuesto | Al cerrar diseño |
| Cableado | Cable HDMI plano A → micro-HDMI con cabezales a 90° | 1 | Necesario | Al cerrar diseño |
| Cableado | Cable micro-USB acodado → USB-A (táctil) | 1 | Necesario | Al cerrar diseño |
| Mecánica | Tornillos M2.5 × 6 autorroscantes (pantalla) | 4 | Necesario | Comprar ahora |
| Electrónica | Adaptador de nivel SN74AHCT125 + resistencia 330 Ω + condensador 1000 µF (LEDs) | 1 | Propuesto | Al cerrar diseño |
| Cableado | Cable USB-C corto solo alimentación (Pololu → Pi 5) | 1 | Necesario | Al cerrar diseño |
| Mecánica | Tornillos M2 × 5 autorroscantes (cámara) | 4 | Necesario | Comprar ahora |
| Mecánica | Tornillos M3 avellanados + insertos M3 (capucha) | 2 | Necesario | Comprar ahora |
| Filamento | PETG o PLA transparente (difusor de la barra y franjas, D033) | poco | Necesario | Comprar ahora |
| Mecánica | Insertos M3 de latón + tornillos M3 × 8 (altavoz, radiador y rebordes) | 16 | Necesario | Comprar ahora |
| Acústica | Junta de espuma de 2 mm (marcos de altavoz y radiador) | 1 | Necesario | Comprar ahora |
| Filamento | TPU (4 patas) | poco | Necesario | Al imprimir |
| Electrónica | Pulsadores táctiles 6 × 6 × 5 mm (volumen −/+, encendido) | 3 | Necesario | Comprar ahora |
| Electrónica | Interruptor deslizante SS12D00 (silencio de micrófonos) | 1 | Necesario | Comprar ahora |
| Mecánica | Tornillos M2 × 6 autorroscantes (placa de botones) | 2 | Necesario | Comprar ahora |
| Filamento | PLA negro mate (carcasa) | 1 kg | Necesario | Comprar ahora |
| Mecánica | Insertos M3 de latón (bandeja 2, caja 4 + 2 traseros, balda 4) | 12 | Necesario | Comprar ahora |
| Mecánica | Tornillos M3 × 80 avellanados (caja superior) | 4 | Necesario | Comprar ahora |
| Mecánica | Tornillos M3 × 10 avellanados (bandeja) | 2 | Necesario | Comprar ahora |
| Mecánica | Tornillos M3 × 35 (balda del KABD) | 4 | Necesario | Comprar ahora |
| Mecánica | Insertos M2.5 + separadores de nailon M2.5 × 3 + tornillos M2.5 × 6 (Pi 5) | 4 | Necesario | Comprar ahora |
| Acústica | Silicona neutra (paso de cables del altavoz) | 1 | Necesario | Al montar |
| Filamento | PETG (caja superior, unos 280 g) | 1 bobina | Disponible | — |

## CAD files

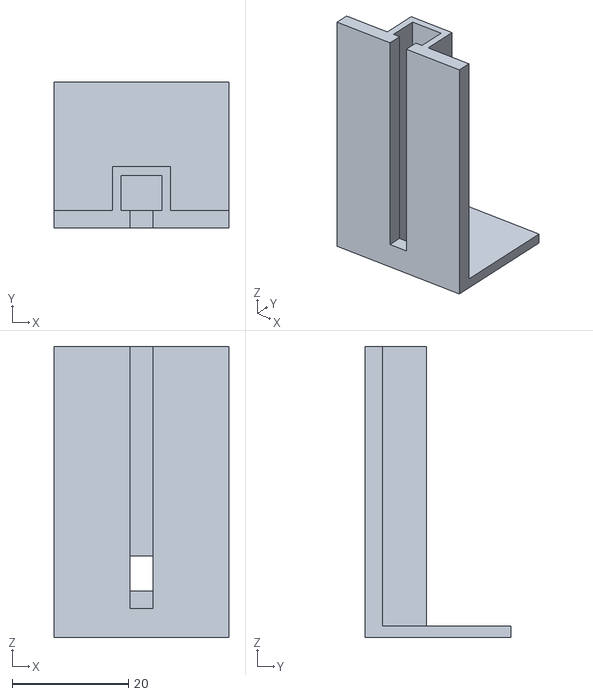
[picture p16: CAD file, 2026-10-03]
stl/prueba_franja_pared_v0_1.stl
30.0 x 25.0 x 50.0

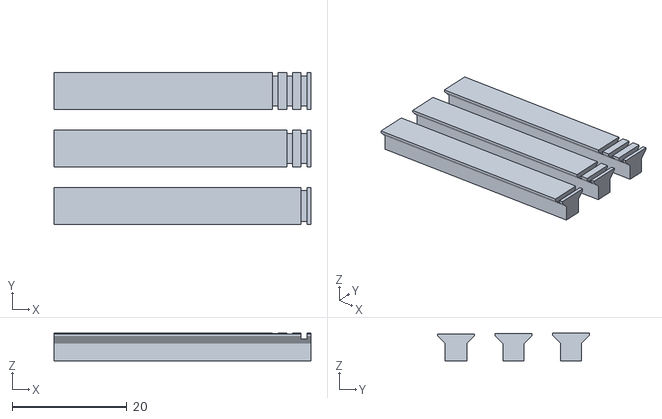
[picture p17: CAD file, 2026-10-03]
stl/prueba_franja_insertos_v0_1.stl
44.7 x 26.4 x 4.80

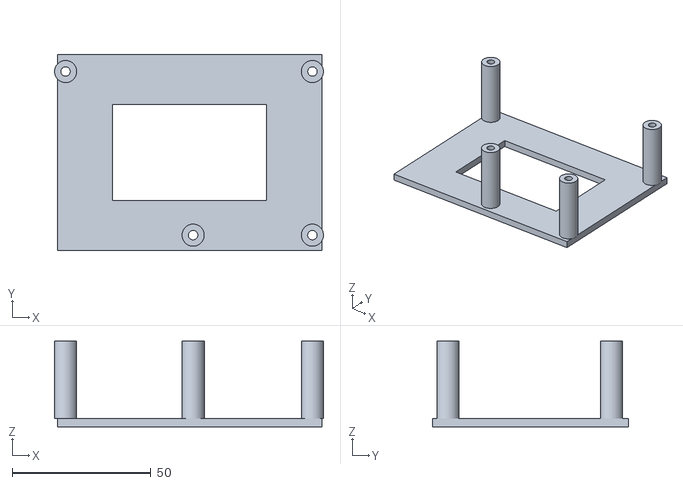
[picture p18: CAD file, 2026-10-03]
stl/balda_kabd_v0_1.stl
97.0 x 70.6 x 31.0

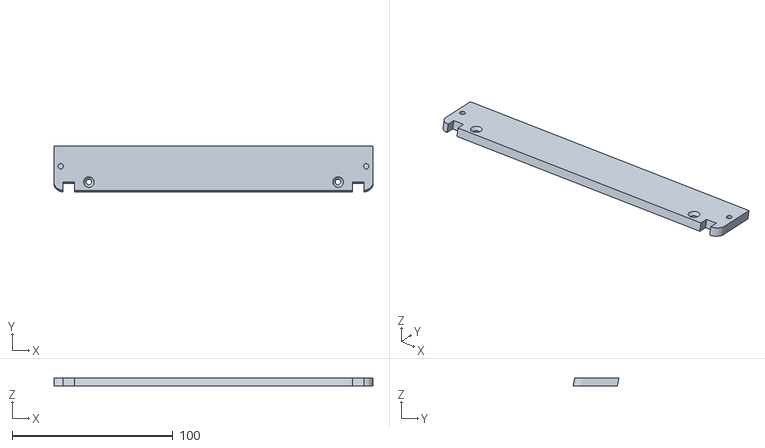
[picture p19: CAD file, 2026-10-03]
stl/bandeja_v0_1.stl
198.4 x 28.5 x 5.00

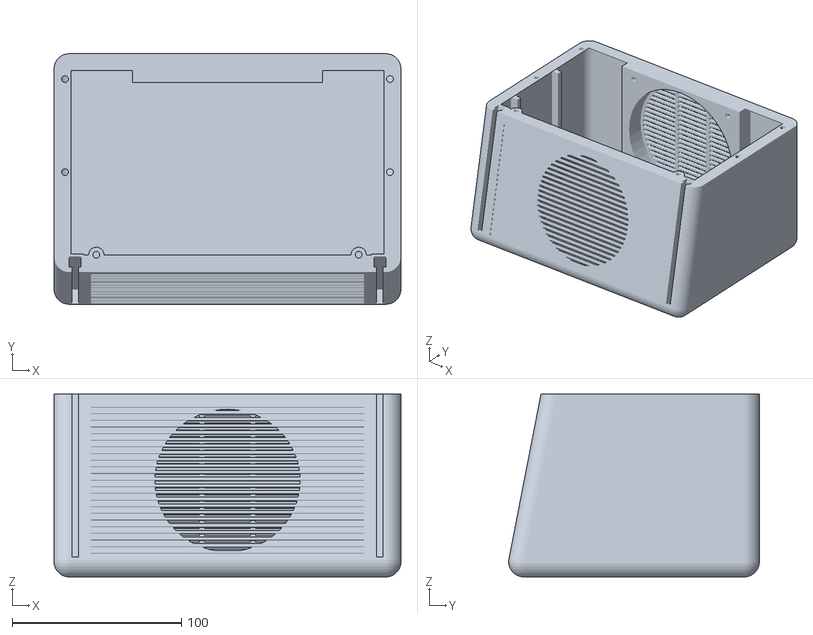
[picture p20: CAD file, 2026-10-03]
stl/cubeta_v0_4.stl
205.0 x 148.1 x 108.0

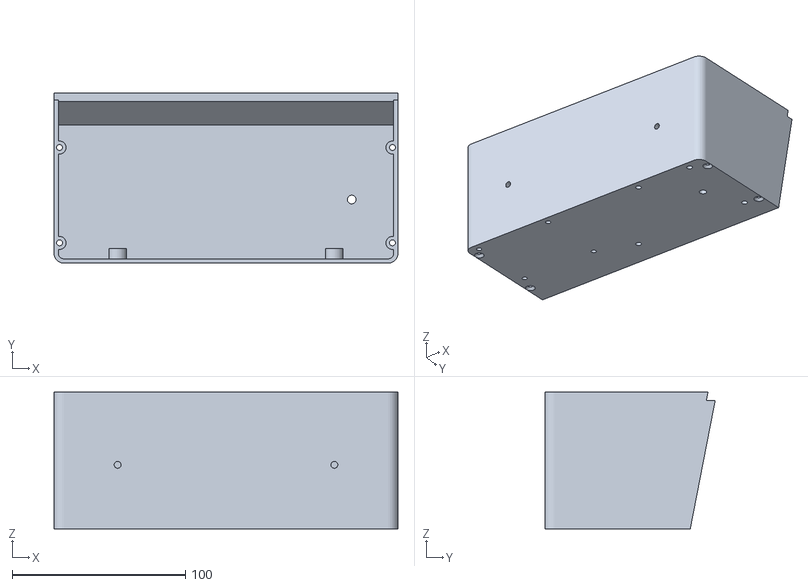
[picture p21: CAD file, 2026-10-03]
stl/caja_superior_v0_1.stl
198.4 x 98.2 x 79.0

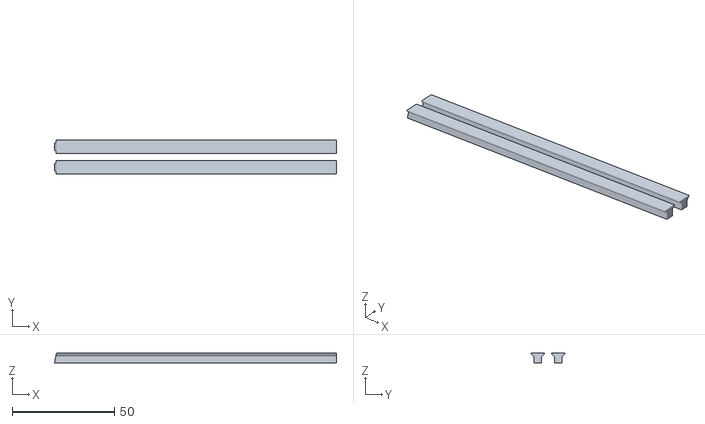
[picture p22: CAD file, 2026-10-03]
stl/franja_sup_v0_1.stl
137.8 x 16.4 x 4.75

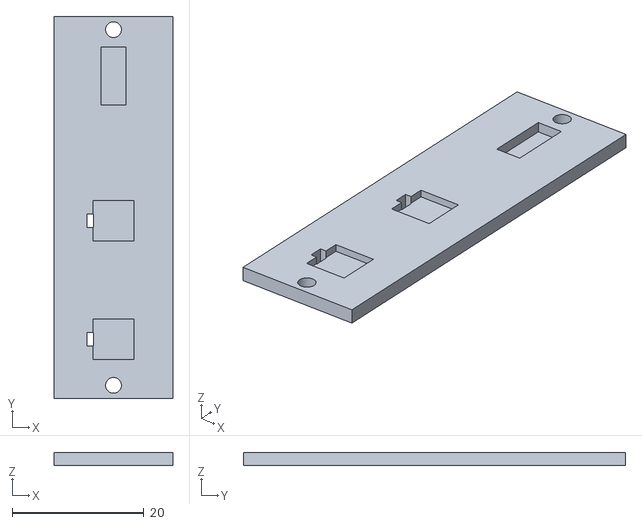
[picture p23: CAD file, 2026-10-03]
stl/placa_botones_v0_1.stl
18.0 x 58.0 x 2.00

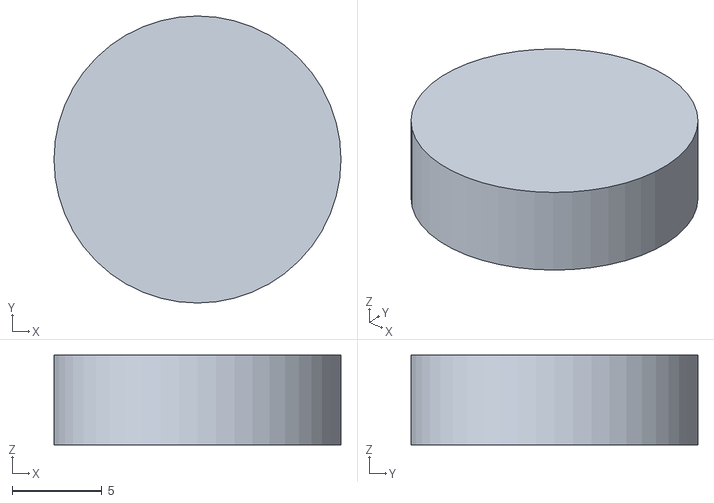
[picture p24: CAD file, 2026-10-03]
stl/pata_tpu_v0_2.stl
16.0 x 16.0 x 5.00

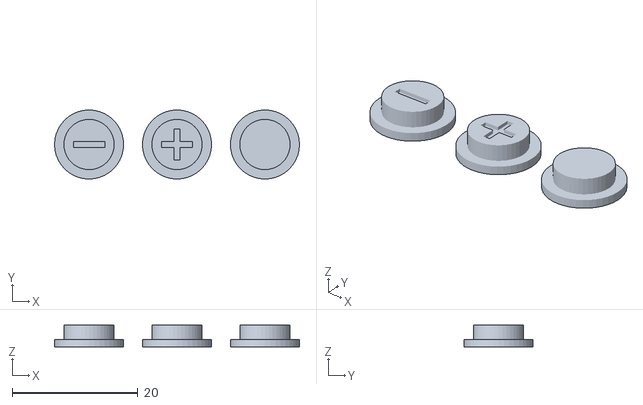
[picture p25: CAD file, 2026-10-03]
stl/capuchones_botones_v0_1.stl
39.0 x 11.0 x 3.50

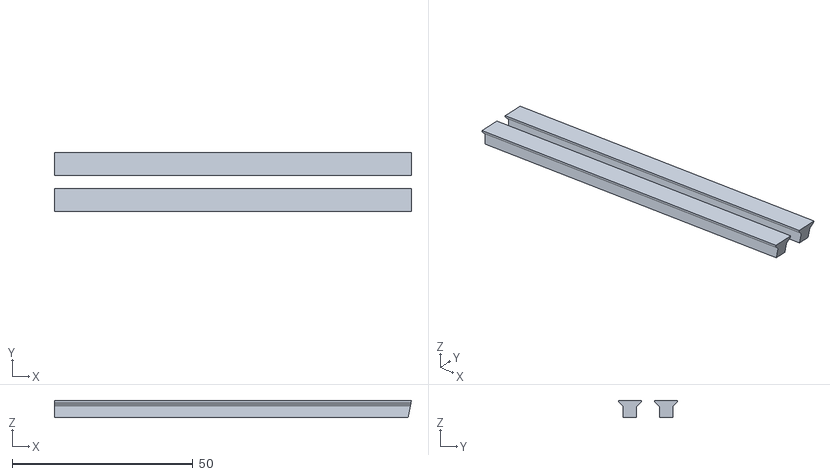
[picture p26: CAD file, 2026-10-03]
stl/franja_inf_v0_1.stl
98.8 x 16.4 x 4.75

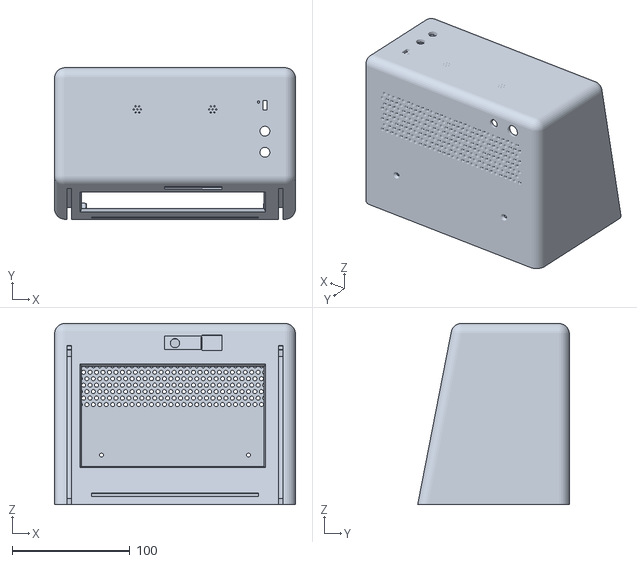
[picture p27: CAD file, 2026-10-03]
stl/capucha_v0_3.stl
205.0 x 129.0 x 154.0

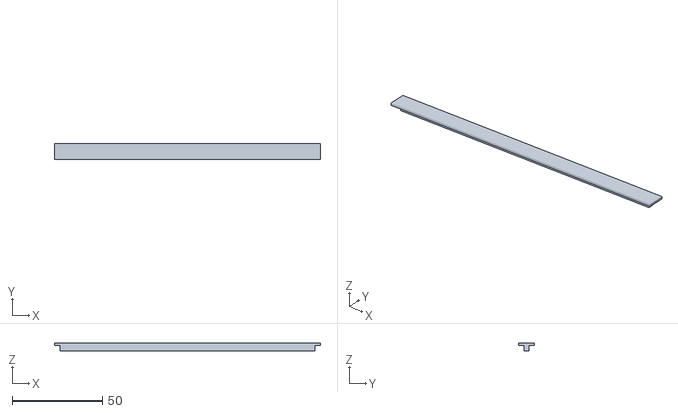
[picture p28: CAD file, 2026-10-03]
stl/difusor_led_v0_2.stl
147.7 x 8.70 x 4.20

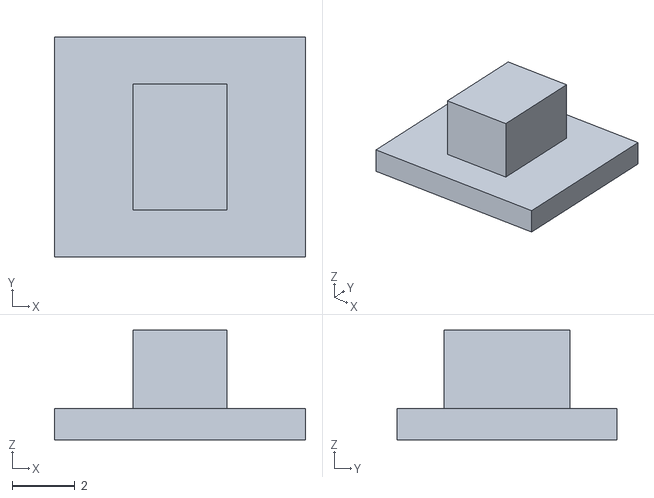
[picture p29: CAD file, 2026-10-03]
stl/deslizador_silencio_v0_1.stl
8.00 x 7.00 x 3.50

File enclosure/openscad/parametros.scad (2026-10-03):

// Prisma v0.5 — todas las cotas en mm
// Ejes: X = ancho (izq→der), Y = fondo (frente→trasera), Z = alto.
// Origen en la esquina frontal-inferior-izquierda de la envolvente.
//
// v0.5 vuelve al boceto original (D031): frontal inclinado continuo de arriba abajo,
// aristas redondeadas, banda de lamas bajo la pantalla y acabado negro mate.
//
// Sistema del frontal: s = distancia a lo largo de la cara exterior inclinada desde la base,
// n = profundidad hacia dentro, perpendicular al frontal.
//   y = s·sen(a) + n·cos(a)      z = s·cos(a) − n·sen(a)

// ---------------------------------------------------------------------------
// Envolvente exterior (D009, D031)
// ---------------------------------------------------------------------------
outer_w = 205;
outer_h = 262;    // altavoz + bandeja + pantalla + cámara apilados en el frontal inclinado
outer_d = 150;    // +5 mm respecto a v0.4 para compensar el volumen que quita el frontal inclinado
corner_r = 9;     // radio de las aristas redondeadas

wall      = 3;    // pared exterior
wall_int  = 5;    // tabiques internos (cámara acústica: más rígidos)

front_angle = 11;               // inclinación del frontal (y de la pantalla y el altavoz)
screen_angle = front_angle;     // alias usado por las piezas de prueba
top_setback = outer_h * tan(front_angle);   // ≈ 50,9

// ---------------------------------------------------------------------------
// Pantalla Waveshare 7" HDMI LCD (C) Rev4.1
// Cotas del PCB, taladros y conectores: plano oficial de Waveshare.
// Cristal y área visible: medidos sobre fotos de la unidad real (±1 mm).
// Montada en HORIZONTAL; mirando de frente, el flex del LCD queda abajo y los
// conectores (HDMI, micro-USB táctil, interruptor de retroiluminación) en el
// canto DERECHO, en la mitad superior.
// Coordenadas locales: x desde el borde izquierdo, z desde el borde inferior de
// las pestañas, y hacia atrás desde la cara del cristal.
// ---------------------------------------------------------------------------
screen_w      = 164.9;   // ancho total (plano)
screen_h      = 124.27;  // alto total con pestañas (plano)
screen_body_h = 106.96;  // alto del PCB entre pestañas (plano)
screen_tab_gap = 148.9;  // hueco entre pestañas (plano)
glass_h       = 99.8;    // alto del cristal (foto)
glass_z0      = 16.4;    // borde inferior del cristal sobre el borde inferior de las pestañas (foto)
screen_t      = 7.9;     // cara del cristal → cara delantera del PCB (medido: 9,5 hasta la trasera del PCB)
screen_pcb_t  = 1.6;
screen_comp_t = 4;       // componentes generales detrás del PCB
screen_active_w = 154.21; screen_active_h = 85.92;   // área visible 1024×600
screen_active_x0 = 3.6;            // margen izquierdo cristal → área visible (derecho ≈ 7,1)
screen_active_z0 = glass_z0 + 9.0; // margen inferior ≈ 9,0 (superior ≈ 4,9)
screen_hole_dx = 156.9; screen_hole_dz = 114.96;    // taladros (plano), a 4,0 mm de los laterales
screen_hole_z0 = (screen_h - screen_hole_dz) / 2;   // 4,655
screen_hole_d = 3.0;     // medido → tornillos M2.5
// Conectores en el canto derecho (plano), desde el borde superior de las pestañas:
// HDMI 18–34 mm, micro-USB táctil 41–49 mm, interruptor 54–62 mm
screen_conn_top = 15;
screen_conn_bot = 65;
screen_conn_proud = 2;
screen_conn_depth = 7;
plug_clear = 15;         // hueco lateral para clavijas acodadas a 90°
screen_s0 = 118.5;       // posición del borde inferior de las pestañas a lo largo del frontal (s)

// ---------------------------------------------------------------------------
// Cámara acústica (D016, D031): bloque inferior de ancho y fondo completos +
// bloque superior-trasero tras un tabique paralelo al frontal (detrás de la pantalla)
// ---------------------------------------------------------------------------
chamber_low_top  = 108;  // techo del bloque inferior = cara inferior de la bandeja = unión cubeta/capucha
part_n           = 26;   // cara delantera del tabique inclinado (profundidad n desde la cara exterior)
chamber_up_top   = 182;  // techo interior del bloque superior-trasero
acoustic_target_l = 3.5;
bracing_allow_l   = 0.10;

// ---------------------------------------------------------------------------
// Audio
// ---------------------------------------------------------------------------
speaker_d = 105; speaker_depth = 48;   // DMA105-4 (marco / fondo total; SoundImports: fondo 47,2 mm)
drv_frame = 104.1; drv_cut = 90;       // marco cuadrado y recorte (3,54") — confirmar con la pieza
pr_frame  = 104.1; pr_cut  = 98.4;     // DMA105-PR: marco y recorte (3,875")
pr_d      = 104; pr_depth  = 55.1;
drv_clear = 7;                          // marco del altavoz a 7 mm de la rejilla (suspensión + Xmax + margen)
pr_clear  = 14;                         // radiador: Xmax 9 mm
bolt_off  = 44.9;                       // taladros en las esquinas, ±44,9 mm — medir
drv_s     = 58.5;                       // centro del altavoz a lo largo del frontal (s)
drv_n     = wall + drv_clear;           // plano del marco del altavoz (n)
audio_center_z = drv_s * cos(front_angle) - drv_n * sin(front_angle);   // ≈ 55,5
pr_flange_y = outer_d - wall - pr_clear;

// Banda de lamas del frontal (D031)
grille_s0 = 12; grille_s1 = 104;        // tramo de la banda a lo largo del frontal
grille_margin_x = 22;                   // la banda ocupa todo el ancho salvo 22 mm por lado

// ---------------------------------------------------------------------------
// Electrónica (bahía superior, sobre la tapa de la cámara)
// ---------------------------------------------------------------------------
bay_floor_z = chamber_up_top + wall_int;   // 187

pi_w = 85; pi_d = 56; pi_h = 25;   // Pi 5 con Active Cooler; USB a la derecha, micro-HDMI/USB-C hacia delante
kabd_w = 91.4; kabd_d = 68.6; kabd_h = 23;
dac_w = 32; dac_d = 14; dac_h = 10;            // GY-PCM5102
buck_w = 25.4; buck_d = 25.4; buck_h = 9.5;    // Pololu D36V50F5
bracket_z = bay_floor_z + pi_h + 3;            // balda del KABD-250
port_clear = 20;

// Entrada DC y botón de encendido en la trasera
dc_d = 11.2; dc_depth = 20;
dc_x = 30; dc_z = bay_floor_z + 58;
power_btn_x = 52; power_btn_z = dc_z;

// Botones del techo (D032): capuchones de 8 mm enrasados sobre pulsadores de 6 × 6 mm,
// e interruptor deslizante de silencio de micrófonos (corta la alimentación USB del ReSpeaker)
btn_cap_d = 8; btn_x = outer_w - 26;
btn_y = [78, 96];               // volumen −, volumen +
mute_y = 118;                   // interruptor deslizante
mute_travel = 4; mute_knob = [3, 4];

// Iluminación y captación
led_bar_w = 140; led_bar_h = 3;
led_s = 117;                    // franja LED a lo largo del frontal (s)
mic_w = 86; mic_d = 35; mic_h = 8;     // ReSpeaker Lite USB
mic_spacing = 64;                      // verificar en la placa
mic_y = 97;
mic_rail_gap = 1.8;

// Franjas de luz en los cantos del frontal (D033): insertos transparentes en una ranura de la
// pared y, detrás, un canal cerrado con una tira WS2812B de 5 mm que da el color según el estado
edge_strip_w  = 4;                      // ancho visible de la franja
edge_strip_xc = corner_r + 1.5 + edge_strip_w / 2;   // centro, desde cada lateral (12,5): justo dentro del redondeo
edge_strip_s0 = grille_s0;              // empieza a la altura de la banda de lamas
edge_strip_s1 = 248;                    // y acaba antes del redondeo del techo
edge_ch_w   = 7;                        // hueco del canal (tira de 5 mm + holgura)
edge_ch_n   = 9;                        // fondo del hueco (la tira queda a ≈6 mm de la cara exterior)
edge_ch_t   = 1.5;                      // paredes del canal
edge_ins_clear = 0.15;                  // holgura por lado de los insertos

// Bandeja (2a) y caja superior (2b) de la cámara acústica (D027, D034)
tray_screw_x = 25;          // 2 tornillos M3 avellanados de la bandeja a insertos en la cubeta (x desde cada lateral)
tray_screw_n = 10;          // ... a 10 mm detrás de la cara exterior del frontal, en z = chamber_low_top
tray_front_gap = 1.0;       // holgura delantera: la capucha baja en vertical y su frontal inclinado avanza ≈1 mm en los últimos 5 mm
box_t   = 2.5;              // paredes de la caja superior (PETG)
box_gap = 0.3;              // holgura entre la caja y la capucha
box_screw_y = [80, 135];    // 4 tubos con tornillos M3 × 80 desde el suelo de la bahía hasta los rebordes de la cubeta
box_screw_x = wall + 3.5;   // centro de los rebordes laterales (6,5)

// Uniones capucha ↔ bandeja delantera (D029)
pin_block = 9; pin_d = 3; pin_len = 4; pin_hole_d = 3.3;
pin_n = 19;     // centro de los pasadores detrás del frontal (y = front_y(z bandeja) + pin_n), tras el canal de las franjas

// Cámara (D025): OV5647 sobre la pantalla
cam_w = 25; cam_h = 24; cam_t = 9;
cam_gap = 1;
cam_lens_d = 8;
cam_hole_dx = 21; cam_hole_dz = 12.5; cam_lens_from_bottom = 14.5;
cam_standoff = 5;
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

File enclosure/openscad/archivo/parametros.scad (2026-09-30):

// Prisma v0.2 — todas las cotas en mm
outer_w=205; outer_h=250; outer_d=145;

// Waveshare — provisionales
screen_w=164.9;
screen_h=124.27;
screen_t=8;
screen_angle=18;
screen_cable_channel=18;

// Pi 5
pi_w=85; pi_d=58; pi_h=18;

// KABD-250 — provisionales
kabd_w=91.4; kabd_d=68.6; kabd_h=23;

// Audio
speaker_d=105; speaker_depth=48;
pr_d=104; pr_depth=53;

// Bloques provisionales
dac_w=45; dac_d=35; dac_h=15;
buck_w=60; buck_d=35; buck_h=20;

acoustic_target_l=3.5;

show_envelope=true;
show_screen=true;
show_electronics=true;
show_audio=true;

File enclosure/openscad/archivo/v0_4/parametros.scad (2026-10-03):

// Prisma v0.3 — todas las cotas en mm
// Ejes: X = ancho (izq→der), Y = fondo (frente→trasera), Z = alto.
// Origen en la esquina frontal-inferior-izquierda de la envolvente.

// ---------------------------------------------------------------------------
// Envolvente exterior (D009, provisional)
// ---------------------------------------------------------------------------
outer_w = 205;
outer_h = 266;   // 250 hasta v0.3.2: +16 mm para alojar la cámara sobre la pantalla (D025)
outer_d = 145;

wall      = 3;    // pared exterior
wall_int  = 5;    // tabiques internos (cámara acústica: más rígidos)
side_taper = 0;   // laterales rectos, como en el render de concepto. Con 8 mm no cabían las clavijas de la pantalla

// Perfil lateral (D015): frontal inferior vertical + frontal superior inclinado
screen_angle  = 18;   // inclinación del frontal superior y de la pantalla
front_split_z = 122;  // altura donde empieza el frontal inclinado
top_setback   = (outer_h - front_split_z) * tan(screen_angle); // ≈ 41,6

// ---------------------------------------------------------------------------
// Pantalla Waveshare 7" HDMI LCD (C) Rev4.1
// Cotas del PCB, taladros y conectores: plano oficial de Waveshare.
// Cristal y área visible: medidos sobre fotos de la unidad real (±1 mm).
// Montada en HORIZONTAL; mirando de frente, el flex del LCD queda abajo y los
// conectores (HDMI, micro-USB táctil, interruptor de retroiluminación) en el
// canto DERECHO, en la mitad superior.
// Coordenadas locales: x desde el borde izquierdo, z desde el borde inferior de
// las pestañas, y hacia atrás desde la cara del cristal.
// ---------------------------------------------------------------------------
screen_w      = 164.9;   // ancho total (plano)
screen_h      = 124.27;  // alto total con pestañas (plano)
screen_body_h = 106.96;  // alto del PCB entre pestañas (plano)
screen_tab_gap = 148.9;  // hueco entre pestañas (plano)
glass_h       = 99.8;    // alto del cristal (foto)
glass_z0      = 16.4;    // borde inferior del cristal sobre el borde inferior de las pestañas (foto)
screen_t      = 7.9;     // cara del cristal → cara delantera del PCB (medido: 9,5 hasta la trasera del PCB)
screen_pcb_t  = 1.6;
screen_comp_t = 4;       // componentes generales detrás del PCB
screen_active_w = 154.21; screen_active_h = 85.92;   // área visible 1024×600
screen_active_x0 = 3.6;            // margen izquierdo cristal → área visible (derecho ≈ 7,1)
screen_active_z0 = glass_z0 + 9.0; // margen inferior ≈ 9,0 (superior ≈ 4,9)
// Taladros de fijación (plano): 156,90 × 114,96 mm entre centros, a 4,0 mm de los laterales
screen_hole_dx = 156.9; screen_hole_dz = 114.96;
screen_hole_z0 = (screen_h - screen_hole_dz) / 2;   // 4,655
screen_hole_d = 3.0;     // medido → tornillos M2.5
// Conectores en el canto derecho (plano), medidos desde el borde superior de las pestañas:
// HDMI 18–34 mm, micro-USB táctil 41–49 mm, interruptor 54–62 mm
screen_conn_top = 15;
screen_conn_bot = 65;
screen_conn_proud = 2;   // el HDMI sobresale ≈2 mm del canto
screen_conn_depth = 7;   // altura del HDMI detrás del PCB (medido)
plug_clear = 15;         // hueco lateral para clavijas acodadas a 90°
screen_margin = 3;       // del inicio del plano inclinado al borde inferior de las pestañas

// ---------------------------------------------------------------------------
// Cámara acústica en L (D016)
// ---------------------------------------------------------------------------
chamber_low_top  = 111;  // techo interior del bloque inferior (ancho completo)
chamber_up_front = 60;   // cara interior frontal del bloque superior-trasero
chamber_up_top   = 176;  // techo interior del bloque superior-trasero
acoustic_target_l = 3.5; // objetivo 3–4 L netos
bracing_allow_l   = 0.10; // reserva para refuerzos, espuma y cableado

// ---------------------------------------------------------------------------
// Audio
// ---------------------------------------------------------------------------
speaker_d = 105; speaker_depth = 48;   // DMA105-4 (marco / fondo total; SoundImports: fondo 47,2 mm)
drv_frame = 104.1; drv_cut = 90;        // marco cuadrado y recorte (3,54") — confirmar con la pieza
pr_frame  = 104.1; pr_cut  = 98.4;      // DMA105-PR: marco y recorte (3,875")
// Montaje por dentro detrás de la rejilla (D030): plano del marco a esta distancia de la cara interior
drv_clear = 7;                          // suspensión (≈3) + Xmax 2,5 + margen
pr_clear  = 14;                         // suspensión (≈4) + Xmax 9 + margen
drv_flange_y = wall + drv_clear;
pr_flange_y  = outer_d - wall - pr_clear;
bolt_off  = 44.9;                       // taladros en las esquinas: ±44,9 mm (círculo de 5" según la tienda) — medir
pr_d      = 104; pr_depth      = 55.1; // DMA105-PR (Dayton: marco 104,1 mm, recorte 98,4 mm, fondo 55,1 mm)
audio_center_z = (wall + chamber_low_top) / 2;  // ≈ 57

// ---------------------------------------------------------------------------
// Electrónica (bahía superior, sobre la tapa de la cámara)
// ---------------------------------------------------------------------------
bay_floor_z = chamber_up_top + wall_int;   // 181

// Pi 5 en orientación normal: USB/Ethernet hacia la derecha (+X), micro-HDMI y USB-C hacia la pantalla (−Y)
pi_w = 85; pi_d = 56; pi_h = 25;   // h con Active Cooler
kabd_w = 91.4; kabd_d = 68.6; kabd_h = 23;
dac_w = 32; dac_d = 14; dac_h = 10;   // GY-PCM5102 (PCM5102A), salida jack 3,5 mm
buck_w = 25.4; buck_d = 25.4; buck_h = 9.5;   // Pololu D36V50F5 (5 V, 5,5 A)
bracket_z = bay_floor_z + pi_h + 3;   // balda para el KABD-250, por encima de Pi, buck y DAC
port_clear = 20;                      // hueco delante de los puertos de la Pi para clavijas acodadas

// Entrada DC (fuente externa 24 V, D003) — conector de panel
dc_d = 11.2; dc_depth = 20;   // conector DC de panel 5,5 × 2,1 (taladro de 11 mm)
dc_x = 30; dc_z = bay_floor_z + 65;   // trasera, por encima de la rejilla

// Iluminación y captación
led_bar_w = 140; led_bar_h = 5;  led_bar_z = 116.5;
// ReSpeaker Lite USB (XU316: 2 micrófonos, AEC, supresión de ruido): placa 86 × 35 mm
// justo bajo el techo, con 2 agujeros en la tapa. El XVF3800 (Ø 99 mm) no cabe con la pantalla inclinada.
mic_w = 86; mic_d = 35; mic_h = 8;     // placa + conectores
mic_spacing = 64;                      // separación aproximada entre micrófonos: verificar en la placa
mic_y = 97;                            // borde delantero de la placa
mic_rail_gap = 1.8;

// Uniones capucha ↔ bandeja delantera (D029): pasadores en las esquinas delanteras
pin_block = 9; pin_d = 3; pin_len = 4; pin_hole_d = 3.3;                    // la placa se desliza en raíles justo bajo el techo
// Cámara (D025): OV5647 5 MP (compatible con la cámara oficial v1.3), centrada sobre la
// pantalla, en el frontal inclinado, mirando al usuario con la misma inclinación que la pantalla.
// La Camera Module 3 tiene la misma placa: para usarla basta con subir cam_standoff y cam_t.
cam_w = 25; cam_h = 24; cam_t = 9;      // placa 25 × 24 mm; fondo total aprox. (OV5647)
cam_gap = 3;                            // separación entre el borde superior del cristal y la placa
cam_lens_d = 8;                         // agujero para el objetivo
// Taladros M2 de la placa (patrón común de las cámaras oficiales: 21 × 12,5 mm).
// El objetivo queda a la altura de la fila superior de taladros, 14,5 mm sobre el borde inferior.
cam_hole_dx = 21; cam_hole_dz = 12.5; cam_lens_from_bottom = 14.5;
cam_standoff = 5;                       // cara interior del frontal → cara delantera de la placa (≈ alto del objetivo OV5647: medir)

// ---------------------------------------------------------------------------
// Visualización
// ---------------------------------------------------------------------------
show_shell       = true;
show_screen      = true;
show_electronics = true;
show_audio       = true;
show_chamber_air = false;  // volumen de aire neto de la cámara (para inspección)
section_x        = false;  // corte por el plano medio X (vista lateral interior)

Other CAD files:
stl/tapa_camara_corredera_v0_2.stl
stl/tapa_camara_prueba_v0_1.stl
stl/marco_pantalla_prueba_v0_1.stl
enclosure/openscad/bandeja.scad
enclosure/openscad/archivo/prisma_volumetrica_v0_2.scad
enclosure/openscad/archivo/v0_4/capucha.scad
enclosure/openscad/archivo/v0_4/cubeta.scad
enclosure/openscad/archivo/v0_4/prisma_volumetrica_v0_3.scad
enclosure/openscad/caja_superior.scad
enclosure/openscad/capucha.scad
enclosure/openscad/cubeta.scad
enclosure/openscad/marco_pantalla_prueba.scad
enclosure/openscad/prisma_volumetrica_v0_3.scad
enclosure/openscad/prisma_volumetrica_v0_5.scad
enclosure/openscad/prueba_franja.scad
enclosure/openscad/tapa_camara_prueba.scad

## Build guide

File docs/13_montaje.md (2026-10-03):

# 13 — Montaje
El procedimiento definitivo se documentará tras cerrar la carcasa. El montaje de la cámara acústica ya está en `16_bandeja_caja.md`.

Orden previsto: estructura → cámara acústica → altavoz/PR → sellado y pasamuros → electrónica (bahía superior) → pantalla → cableado por el canal trasero de la pantalla → micrófonos/LEDs → pruebas.

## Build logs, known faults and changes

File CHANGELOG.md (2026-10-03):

# Changelog
## v0.6
- Bandeja (2a) y caja superior (2b) de la cámara acústica, y balda del KABD-250 (D034): `bandeja_v0_1.stl`, `caja_superior_v0_1.stl`, `balda_kabd_v0_1.stl`. Ver `docs/16_bandeja_caja.md`.
- Cubeta v0.4: reborde delantero para la bandeja, 2 resaltes con inserto y los insertos de los rebordes laterales en y = 80 y 135 mm para los tornillos de la caja.
- Pieza de prueba de las franjas (`prueba_franja_pared_v0_1.stl` + `prueba_franja_insertos_v0_1.stl`, 3 holguras).
- Nuevo `tools/comprobar_camara.py`. Volumen neto medido con todas las piezas: 3,08 L (simulación sin cambios apreciables).

## v0.5.1
- Franjas de luz en los dos cantos del frontal (D033): insertos impresos en filamento transparente y tiras WS2812B de 5 mm detrás, en un canal cerrado separado de la cámara acústica. El color depende del estado del asistente (tabla en `docs/11_software.md`).
- Difusor de la barra LED en transparente.
- Capucha v0.3 y cubeta v0.3 con las ranuras y los canales; nuevos insertos `franja_inf_v0_1.stl` y `franja_sup_v0_1.stl`.
- Pasadores capucha ↔ bandeja 19 mm por detrás del frontal para dejar sitio al canal; la bandeja lleva una muesca que cierra el canal.
- Consumo de los LEDs limitado por software a 0,6 A. Cámara: ≈3,11 L netos.

## v0.5
- Vuelta al boceto original (D031): frontal inclinado 11° continuo, aristas redondeadas, banda de lamas a todo lo ancho bajo la pantalla, laterales lisos y acabado negro mate. Envolvente 205 × 262 × 150 mm.
- Nuevo volumétrico `prisma_volumetrica_v0_5.scad`: altavoz en el frontal inclinado; parte alta de la cámara acústica tras un tabique paralelo al frontal; ≈3,13 L netos.
- Capucha v0.2: perforado trasero, botones en el techo (capuchones de 8 mm y silencio deslizante), botón de encendido trasero (D032).
- Cubeta v0.2: banda de lamas (pasante solo delante del cono), anillo de montaje inclinado.
- Las comprobaciones de capucha y cubeta usan manifold3d (mucho más rápidas).
- v0.4 (capucha y cubeta con estrías) archivada en `enclosure/openscad/archivo/v0_4/`.

## v0.4.1
- Cubeta acústica v0.1 imprimible (`stl/cubeta_v0_1.stl`): rejilla de ranuras integrada delante y detrás, altavoz y radiador montados por dentro sobre anillos, rebordes para la bandeja y la caja superior, refuerzos y patas de TPU (D030).
- Parte alta de la cámara más grande (techo 176 mm, pared delantera en 60 mm) para compensar los anillos: ≈3,1 L netos finales.
- Nuevo `tools/comprobar_cubeta.py`; altavoz y radiador del volumétrico en su posición real.

## v0.4
- Capucha v0.1 imprimible (`stl/capucha_v0_1.stl`): estrías de 4 mm, rejillas integradas, ventana y resaltes de la pantalla, cámara con guía de tapa, ranura y difusor LED, micrófonos con raíles, conector DC, ventilador opcional y uniones.
- División de la carcasa en 4 piezas (D027), estrías (D028) y uniones (D029).
- Cámara: OV5647 (la que hay); el soporte admite también la Camera Module 3.
- Nuevo `tools/comprobar_capucha.py`.

## v0.3.3
- Cámara Raspberry Pi Camera Module 3 centrada sobre la pantalla, en el frontal inclinado (D025).
- Carcasa 16 mm más alta (250 → 266 mm) para alojarla; la cámara acústica no cambia.
- Tapa deslizante de privacidad (D026) con pieza de prueba: `stl/tapa_camara_prueba_v0_1.stl`.

## v0.3.2
- Electrónica propuesta: DAC GY-PCM5102, ReSpeaker Lite USB, Pololu D36V50F5 y Mean Well GST60A24 (D011–D014), con presupuesto de consumo y cableado en `docs/10_electronica.md`.
- LEDs por SPI con adaptador de nivel (D023); cancelación de eco (D024); filtro paso alto en la Pi (D022).
- Simulación de graves (`tools/simulacion_audio.py`): radiador pasivo con ≈10 g, sintonía ≈43 Hz.
- Modelo: DAC, conversor y micrófonos con sus medidas reales; ventilación trasera y lateral; cámara opcional sin posición.

## v0.3.1
- Pantalla con las cotas del plano oficial de Waveshare: 124,27 mm de alto con pestañas, taladros a 156,90 × 114,96 mm y posición exacta de HDMI, micro-USB e interruptor.
- PCB modelado con pestañas y hueco central.
- Medidas de calibre: taladros de 3,0 mm (→ M2.5) y grosor de 9,5 mm + 7 mm del HDMI.
- Marco de pantalla de prueba imprimible: `enclosure/openscad/marco_pantalla_prueba.scad` y `stl/marco_pantalla_prueba_v0_1.stl`.

## v0.3
- Nuevo perfil lateral: frontal inferior vertical + frontal superior inclinado 18° para la pantalla (D015).
- Cámara acústica en L: ≈3,3 L netos medidos sobre el modelo. Con el esquema de v0.2 se quedaba en ≈2,5 L (D016).
- Electrónica en bahía superior. Ventilación pasiva solo en esa zona, sin ventilador junto a la cámara (D017).
- DMA105-PR en la trasera inferior, sin puertos ni rejillas delante (D018).
- Sin fuente interna: entrada DC 24 V de panel (D003, D019).
- Micrófonos y cámara opcional en el techo, zona delantera (D020).
- Pantalla modelada con medidas de la unidad real: cristal, pestañas, taladros, área visible descentrada y conectores en el canto derecho.
- Laterales rectos y 15 mm libres para las clavijas acodadas de la pantalla (D021).
- Bahía reorganizada: Pi 5 en orientación normal con huecos de 20 mm para clavijas; KABD-250 en una balda superior.
- Script `tools/comprobar_volumetrico.py`: volumen de la cámara + interferencias.
- Vistas en `docs/img/`.
- Corregido: en v0.2 el altavoz y el radiador se rotaban dos veces y quedaban fuera de la caja.
- Limpieza: quitados archivos del proyecto Steam Machine que se colaron (`00_parametros.scad`, `GUIA_INICIO.md`); `.gitignore` y `VERSION.md` reescritos para Prisma; LICENSE con titular; `hardware/BOM.csv` convertido a CSV real.
- v0.2 archivada en `enclosure/openscad/archivo/`.

## v0.2
- Raspberry Pi 5 8 GB.
- Waveshare 7" como referencia física principal.
- Envolvente inicial 205×250×145 mm.
- Cámara acústica separada de electrónica.
- Alimentación externa 24 V.
- DMA105-4 + DMA105-PR como arquitectura acústica propuesta.
- KABD-250 como amplificador propuesto.
- Estructura inicial de GitHub.

## v0.1
- Primera maqueta volumétrica.

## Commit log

2026-09-30 Prisma v0.3: volumétrico nuevo, pantalla con medidas reales y limpieza del repo
    - Perfil: frontal inferior vertical + frontal superior inclinado 18°, laterales rectos.
    - Cámara acústica en L, ≈3,3 L netos medidos sobre el modelo.
    - Electrónica en bahía superior, sin fuente interna; DMA105-PR en la trasera inferior.
    - Waveshare 7" en horizontal con medidas de la unidad real y conectores en el canto derecho.
    - tools/comprobar_volumetrico.py: volumen de la cámara + interferencias.
    - Docs, decisiones D015–D021 y BOM actualizados.
    - Quitados archivos del proyecto Steam Machine; .gitignore, VERSION, LICENSE y BOM.csv corregidos.
    C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
    [00_parametros.scad, BOM.csv, parametros.scad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]
2026-09-30 Pantalla: cotas del plano oficial de Waveshare
    Alto con pestañas 124,27 mm, taladros 156,90 × 114,96 mm y posición de
    HDMI, micro-USB e interruptor según el plano. Comprobación sin interferencias.
    Claude-Session: https://claude.ai/code/session_011wCrvR5XLZziNZnBQxWkpT
    [parametros.scad, prisma_volumetrica_v0_3.scad]
2026-09-30 Marco de pantalla de prueba y medidas de calibre
    Taladros de 3,0 mm (M2.5) y grosor medido. Marco imprimible para
    comprobar el encaje de la Waveshare antes de imprimir la carcasa.
    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
    [BOM.csv, marco_pantalla_prueba.scad, marco_pantalla_prueba_v0_1.stl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]
2026-09-30 Simulación de graves: DMA105-4 + DMA105-PR en 3,3 L
    Modelo Thiele-Small con parámetros de Dayton. Recomienda ~10 g de masa
    en el PR (sintonía ~43 Hz) y filtro paso alto a ~40 Hz en el DSP.
    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
    [parametros.scad]
2026-09-30 Electrónica: DAC, micrófonos, conversor y fuente
    GY-PCM5102, ReSpeaker Lite USB, Pololu D36V50F5 y Mean Well GST60A24,
    con presupuesto de consumo, cableado y modelo actualizado.
    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
    [BOM.csv, parametros.scad, prisma_volumetrica_v0_3.scad]
2026-09-30 Cámara sobre la pantalla (Camera Module 3) y carcasa de 266 mm
    La franja sobre el cristal medía 12 mm y la placa 24 mm: la carcasa
    crece 16 mm. La cámara acústica no cambia (≈3,3 L).
    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
    [BOM.csv, parametros.scad, prisma_volumetrica_v0_3.scad]
2026-09-30 Tapa deslizante de privacidad para la cámara (D026)
    Guía en cola de milano en el frontal y pieza de prueba imprimible.
    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
    [prisma_volumetrica_v0_3.scad, tapa_camara_prueba.scad, tapa_camara_prueba_v0_1.stl]
2026-09-30 Capucha v0.1 imprimible con estrías de 4 mm
    División de la carcasa en 4 piezas, capucha con rejillas integradas,
    pantalla, cámara OV5647 con tapa, LEDs, micrófonos, DC y uniones.
    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
    [BOM.csv, capucha.scad, capucha_v0_1.stl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]
2026-10-01 Cubeta acústica v0.1 con rejilla integrada
    Altavoz y radiador montados por dentro sobre anillos de 7 y 14 mm,
    rebordes para la bandeja y la caja superior, refuerzos y patas de TPU.
    Cámara ≈3,1 L netos finales.
    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
    [BOM.csv, capucha_v0_1.stl, cubeta.scad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]
2026-10-03 v0.5: vuelta al boceto original
    Frontal inclinado continuo, aristas redondeadas, banda de lamas a todo
    lo ancho, laterales lisos y negro mate (205 × 262 × 150 mm). Capucha y
    cubeta rehechas, botones en el techo y encendido trasero. Cámara
    acústica ≈3,13 L netos; sin interferencias.
    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
    [BOM.csv, capucha.scad, capucha_v0_1.stl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]
2026-10-03 v0.5.1: franjas de luz transparentes en los cantos (D033)
    - Ranura de 4 mm en cada canto del frontal, justo dentro del redondeo, con
    insertos impresos en filamento transparente (franja_inf / franja_sup).
    - Detrás, canal cerrado para una tira WS2812B de 5 mm (160 LED/m), separado
    de la cámara acústica; la bandeja lo cierra entre z 108 y 113.
    - Pasadores capucha-bandeja 19 mm detrás del frontal para dejar sitio al canal.
    - Difusor de la barra en transparente; tabla de estados y colores en 11_software.
    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
    [BOM.csv, capucha.scad, capucha_v0_2.stl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]
2026-10-03 v0.6: bandeja, caja superior y balda del KABD (D034)
    - Bandeja (2a): placa de 5 mm sobre un reborde delantero nuevo de la cubeta,
    2 tornillos M3, agujeros de los pasadores y muescas del canal de las franjas.
    - Caja superior (2b, PETG): tabique, laterales, trasera y tapa; 4 tubos con
    tornillos M3 x 80 a los rebordes de la cubeta; resaltes de los tornillos
    traseros de la capucha; paso de cables del altavoz; insertos ciegos para la
    Pi 5 y la balda del KABD-250.
    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
    [BOM.csv, balda_kabd_v0_1.stl, bandeja.scad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]
2026-10-14 Pantalla: correcciones del marco de prueba (D035)
    - PCB y taladros 2,5 mm a la izquierda (vista frontal) respecto al cristal,
    medido con el marco de prueba v0.1: capucha v0.4 y volumétrico.
    - Marco de prueba v0.2: la v0.1 se generaba en espejo (al imprimirse boca
    abajo la ventana quedaba desplazada: 4 mm de borde negro a la derecha).
    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
2026-10-14 Pantalla: el desplazamiento del PCB es vertical, no horizontal
    Los resaltes quedaban 2,5 mm más abajo que los taladros del PCB (con el flex
    abajo). screen_pcb_dx = -2.5 pasa a screen_pcb_dz = +2.5 en el marco de
    prueba, la capucha y el volumétrico.
    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
2026-10-16 Software: puesta en marcha de la Raspberry Pi 5
    - docs/17_raspberry.md: grabar el sistema, conexiones, configuración base,
    comprobación de pantalla y cámara, y el cerebro con Claude por la API (D036).
    - software/instalacion/01_base.sh y prueba_camara.sh.
    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
2026-10-16 Software: cerebro 100 % local en la Pi y multimedia (D036)
    Enrutador de órdenes sin IA para lo habitual, modelo pequeño con Ollama solo
    para la charla libre, SearXNG para Internet, faster-whisper y Piper.
    Tiempos de respuesta estimados por tipo de petición. Multimedia: mpv + yt-dlp,
    Spotify Connect, AirPlay y Bluetooth; Amazon Music por el reproductor web.
    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
2026-10-16 Software: paso 2, IA local y SearXNG; sin Amazon Music
    - 02_ia.sh: Ollama (modelo siempre cargado, solo local) con qwen3.5:2b,
    qwen3:1.7b y qwen2.5:3b (gemma4:e2b opcional); Docker y SearXNG en JSON.
    - prueba_ia.py: compara modelos midiendo la primera frase completa, charla
    por texto y prueba de búsqueda con SearXNG.
    - D036 cerrada: Spotify Premium, sin Amazon Music.
    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
2026-10-17 02_ia.sh: reinstala Ollama o Docker si falta su servicio
    Si la conexión se corta a mitad, queda el programa instalado pero sin el
    servicio, y el script lo daba por instalado.
    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
2026-10-18 Modelo definitivo: qwen3:1.7b (D038)
    02_ia.sh descarga solo qwen3:1.7b (--comparar para los candidatos).
    Resultados de la Pi 5 en docs/17_raspberry.md.
    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
2026-10-18 Enrutador: erratas y preguntas de seguimiento; ajustes de tiempo y hora
    - corrige(): palabras clave con erratas («titukares» → «titulares»).
    - Seguimiento: «¿y mañana?», «¿y en Bilbao?», «¿y de TV3?», «¿y el Athletic?».
    - Tiempo: no contradice llovizna con «sin lluvia prevista».
    - Hora: «del mediodía» de 12 a 15 h.
    - --configurar-noticias muestra también los RSS fijos.
    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
2026-10-22 Pantalla: taladros según la medida real respecto al cristal (D043)
    Medido en la pantalla: centro del taladro izquierdo a 8 mm del borde izquierdo del cristal y del inferior
    a 10 mm por debajo del cristal (centros 156,9 × 114,96). El PCB queda 4 mm a la derecha del cristal.
    - parametros.scad: screen_hole_glass_x/below, screen_holes, screen_pcb_dx; screen_pcb_dz derivado (1,745)
    - Marco de prueba v0.4 (175,5 × 130,9 mm) con los resaltes en esa posición
    - Capucha v0.5: mismos resaltes; pantalla 2 mm a la izquierda del centro y plug_clear 13 mm para que
    los conectores, ahora más a la derecha, no choquen con la pared. Comprobadores sin interferencias.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
2026-10-23 Pantalla: taladros 2,5 mm arriba y 5 mm a la izquierda tras la plantilla (v0.5)
    Con la plantilla v0.4 montada, los taladros de la placa quedaban 2,5 mm más arriba y 5 mm a la derecha
    vistos por detrás (a la izquierda vistos de frente). Taladro izquierdo a 3 mm del cristal e inferior a
    7,5 mm por debajo. El PCB queda casi alineado con el cristal: capucha con la pantalla centrada otra vez
    y 15 mm para las clavijas. Marco y plantilla v0.5, capucha v0.6; comprobadores sin interferencias.
    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
